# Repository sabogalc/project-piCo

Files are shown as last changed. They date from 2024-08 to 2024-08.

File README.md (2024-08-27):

# project piCo

This repository contains KiCad project files for reverse-engineered Raspberry Pi Pico boards, including both the standard RP2040 Pico H and the WiFi version, the Pico WH. There is also a preliminary design for an RP2350 Pico 2 board. The primary goal of this project is two-fold:

1. USB-C Upgrade: Although all Pico boards were released in or after 2021, they all use Micro-USB. The initial aim was to update these boards to include USB-C, making them more compatible with modern standards.

2. Accessibility of Design Files: During this process, I discovered that the original board designs are created in Cadence Allegro, a format that is less accessible due to its encrypted file structure and the expensive software required. This project not only adds USB-C support but also aims to make the design files as free and open as possible.

For detailed information on each board’s design, please refer to their specific folders within the `KiCad Projects` directory. Boardview files for all boards, including the original Pico H, are provided to allow for easy troubleshooting. The designs in this repository are freely available for use without any license restrictions or attribution requirements.

> The USB-C version of the Pico H board.


> The USB-C version of the Pico WH board.


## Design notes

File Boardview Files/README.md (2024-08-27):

# Boardview Files

### What is a boardview file?

A boardview file is a netlist of all the connections on a PCB with every component laid out exactly as it is in real life. This is a much more modern and easy approach to viewing connections and approaching troubleshooting than sifting through a schematic to figure out which parts and nets need to be connected to each other.

### How can I view these files?

Much like how there are many PCB EDA softwares out there, there are also many board viewing softwares. The two that I have used and recommend are the MIT licensed [OpenBoardView](https://github.com/OpenBoardView/OpenBoardView) or the commercial (with free version available) [FlexBV](https://pldaniels.com/flexbv/). Below is a screenshot of the Type-C Pico boardview when viewed from FlexBV.

Pico Boardview

You can see the VBUS net is selected, and everywhere that VBUS is present on the board lights up in green. There is also a table of every component and its pin number that has VBUS on the right-hand side. Other important information seen in this boardview is the designators for each part, as well as the value of every resistor and capacitor and the footprint for every component.

All of this metadata comes from the `.obdata` file, and as of August 2024, this metadata is only viewable in FlexBV, which is why I use it as opposed to OpenBoardView. However, the `.obdata` file format is an [open file format and initiative](https://openboarddata.org/), and I would very much like to see the feature added to OpenBoardView.

### How can I make boardview files for my own designs?

All of the boardview files I make for my projects are using [an open-source KiCad plugin](https://github.com/whitequark/kicad-boardview). When I first came across this plugin, it had a few bugs with current versions of KiCad, so I submitted some pull requests and the plugin is back into perfect operating condition. The `.obdata` generation script is currently internal since I made a bit of a mess [submitting that PR](https://github.com/whitequark/kicad-boardview/pull/16), but I am looking to release it eventually.

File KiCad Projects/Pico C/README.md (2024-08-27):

# project piCo

This is a completely reverse-engineered Raspberry Pi Pico H made in KiCad version 8. The Raspberry Pi Foundation offers schematics and board layout files for the original board, but they are made in Cadence Allegro, which costs a crisp $1,500/month that I do not have. Instead, I opted to recreate the board in KiCad so that I could add a Type-C port.

### Overview

Initially, I developed a PCB to convert the original Micro-USB signals to a Type-C breakout board. However, the tolerances were really tight, and it didn't look like much of a finished product. My boss gave me a suggestion to redesign the entire board and add a Type-C port to it, which is what I ended up doing. I started the process with the original design files, which you can find in the section below.

### Design Sources

- **Schematic:** [Raspberry Pi Pico Datasheet](https://datasheets.raspberrypi.com/pico/pico-datasheet.pdf#page=26)
- **PCB Design Files:** [RPi Pico R3 Files](https://datasheets.raspberrypi.com/pico/RPi-Pico-R3-PUBLIC-20200119.zip) (Note: This link will download files directly.)
- **BOM:** [Pico Bill of Materials](https://archive.is/NHUY5)

The mechanical layout provided by the Pi Foundation was extremely useful in creating my board dimensions. Since my footprint was made in KiCad, anybody should be able to implement it for their own projects.

### Footprint Differences

The project includes a footprint named "CON_PICO_40W," which replicates the original footprint, and a modified version, "CON_PICO_40W_VER_C," which is used in my design. Key differences are highlighted below.

Footprint Image

### Design Evolution

Version 1 of the board had many issues. You can see that version [here](https://github.com/sabogalc/project-piCo/tree/4ffbc08c13815f0195cdc85224667cf2c5e13563). The biggest challenge was fitting the Type-C port within the original dimensions.

When I published this project, many people let me know that Type-C Pico clones already exist, so I modeled my redesign after the purple clone board from [this AliExpress listing](https://www.aliexpress.com/item/3256805444428998.html).

AliExpress Board

The revised design removed the 4 mounting holes and added space for the Type-C port, which vastly improved my ability to design and route this board. The "CON_PICO_40W_VER_C" footprint used in this revision is a copy of the purple clone board. Sometimes you just need to [reverse-engineer the reverse-engineers](https://youtu.be/FVEQJNRmfDQ?t=431).

### Component Substitutions

I could not find the original boot select switch, Schottky diode, or 12MHz crystal in stock anywhere, but the substitutions I made should be plug-and-play.

### PDF Schematic

For those of you without KiCad or that just want to take a quick look at the schematic, a [PDF version](https://github.com/sabogalc/project-piCo/blob/main/KiCad%20Projects/Pico%20C/RPI-PICO-R3a-PUBLIC.pdf) is available.

### Version 4 - A 1:1 recreation

[Version 3](https://github.com/sabogalc/project-piCo/tree/0116e01858a51d29eb83f16cde15d637a825e509) of this board improved on [version 2](https://github.com/sabogalc/project-piCo/tree/e2333728981e60bb3f34c05a658cf739d1d45163) in regards to copper pours, routing, and silkscreen labeling. However, versions 1-3 were all routed from scratch by myself. As seen below in the `Official Files` section or in the [piCo W folder](https://github.com/sabogalc/project-piCo/tree/main/KiCad%20Projects/Pico%20WH%20-%20No%20License), I later learned how to convert a Cadence Allegro board into a KiCad one, and this allows me to make a 1:1 PCB when reverse-engineering. Version 4 is this 1:1 render, and it should theoretically be the last version of this board.
Version 4 Render

When it comes to improving the Pico, I have thought about making design improvements to the ADC or adding a reset switch. However, the overall purpose of this project is to be 1:1 with the layout and parts of an original Pico, though if anyone finds any room for improvement I would be happy to make any fixes (e.g. the grid on the schematic is not standard and could use correction).

_**DISCLAIMER**_

I have interned at this company for almost two years.

For those of you that want a board with the aforementioned improvements, check out the [RP2040 board from Out of the Box](https://www.ootbelec.com/store/p/ootb-rp2040).

### Official Files

I have updated this folder to include a file called `RPI-PICO-R3a-PUBLIC - Official.kicad_pcb`. This is as close to the original Cadence Allegro design file that I could get imported into KiCad. I first converted the Allegro board into an Altium one, and then I converted the Altium board into KiCad.

Converted Design
Coverted Design Close-up

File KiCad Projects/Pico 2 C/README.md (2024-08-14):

# project piCo 2

I was extremely excited to see the announcement of the Pico 2 last week, but some of my enthusiasm left me when I saw that the new board still retained the Micro-USB connector. Of course, I got right to work on correcting this issue.

### Design Sources

Despite the online documentation and datasheet linking to design files for the board, the link appears to be broken as of August 14, 2024. (See [this issue](https://github.com/raspberrypi/documentation/issues/3809) for more information)

Still, I worked with the schematic and pictures of the board to be able to create an initial version of a Type-C Pico 2.

- **Schematic:** [Raspberry Pi Pico 2 Datasheet](https://datasheets.raspberrypi.com/pico/pico-2-datasheet.pdf#page=23)
- **PCB Pictures (Front & Back):** [Pico 2 PCB Photos](https://blog.zonepi.cz/rapsberry-pi-pico-2/)

Thankfully, with all the work I've already done on reversing the Pico, making this board was a breeze as I was able to reuse many of my assets and resources from the previous boards.

### Design Process

Kicad allows for Reference Images to be placed while routing a board (found in `Place > Add Reference Image`), so I put the aforementioned scans into the project to scale, and based my routing on the photo. This means that my board is not fully 1:1 with the factory one, but in lieu of the official design files, this was the best that could be done right now. An example of this layout is shown below.


### Component Substitutions (IMPORTANT)

As-is, this board is not ready for production. I was unable to figure out what component or footprint L2 is, other than that it is a coupled inductor and measures roughly 1.75x2.2mm. As a stand-in, I have placed an 0602 SMD inductor, but please note that this is **_not correct_**. As before, the boot select switch and 12MHz crystals are compatible substitutes (even though they told us what crystal was used this time, I just reused the asset I already had from the previous design).

### PDF Schematic

A PDF copy of the schematic is available [here](https://github.com/sabogalc/project-piCo/blob/main/KiCad%20Projects/Pico%202%20C/Pico%202%20C.pdf).

### Board Photos

Because of the aforementioned inductor issue, the only photos of this board right now are the KiCad renders. If anybody figures out what inductor this is, please either let me know or make a correction in the form of a pull request.




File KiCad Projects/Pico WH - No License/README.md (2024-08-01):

# project piCo W

After a few months of making projects with the Pico, I found myself wanting to utilize some of the features offered by the Pico W. However, this meant that I would need to give the same USB-C reverse-engineering treatment to this board, so I took what I learned from my first go and remade the Pico WH as best I could. 

### Design Sources

- **Schematic:** [Raspberry Pi Pico W Schematic](https://wiki.amperka.ru/_media/products:raspberry-pi-pico-w:raspberry-pi-pico-w-schematic.pdf)
- **PCB Design Files:** [RPi PicoW Files](https://datasheets.raspberrypi.com/picow/RPi-PicoW-PUBLIC-20220607.zip) (Note: This link will download files directly.)

This time, rather than making my own board layout, I tried to follow the factory layout as closely as possible. Similarly to the [Official Files](https://github.com/sabogalc/project-piCo/tree/main/KiCad%20Projects/Pico%20C#official-files) section of the original Type-C Pico, I converted the factory Allegro files into a KiCad file (with an Altium conversion in between the two).

Converted Design Close-Up

I then used this converted board as the starting point for my board, so the final result is much closer to the original design. Unfortunately, I cannot release either the converted board or my initial design at this time for reasons that I will explain below.

### The Patent

On page 2 of the schematic, there is a note by the antenna arrangement that reads
> The Niche is an Abracon/Proant patented antenna technology. Please contact niche@abracon.com for information on licensing.

I sent an email explaining my project and how it wasn't commercial in any capacity, asking if there was any kind of fee I could pay to be able to release the board as is. The reponse I got read

> The licensed version of Niche is aimed for high volumes (>100kpcs), and there is a royalty fee/pcs which is agreed per project/customer. The idea is that it should be a very cost-effective solution for high-volume production. It is not an open-source solution which can be used without agreement with Abracon.

They did offer an alternative in the form of a stamped metal antenna that worked virtually identically and came with no license requirement, so I remade the board around this footprint (which is the one you can find in this folder). I found the patent [here](https://patentimages.storage.googleapis.com/39/da/99/a6a16469f1c9ba/US10910715.pdf), and though I am not a legal or patent expert, my understanding is that by 35 U.S.C. 154(b), this patent will expire on March 11, 2038, after which I will be okay to release all of the designs.

### Design Process

Though I am not releasing the design that is barred by the patent, I will still show photos of the final version of that board, and I have also released the boardview file for that board (neither one of these are remotely close to a finished PCB, so I'm sure that is fine). Below is a photo of both boards, with the royalty-free design on the left and the closer 1:1 design on the right.



My design process was essentially Alt+Tabbing between a window that had the converted Allegro design and my blank PCB and just building it up piece by piece while following the design specifications from the import. I did have to make some changes in order to get the board manufactured such as slightly decreasing the diameter of the BGA balls for the WiFi chip, but the final result is still very close to the original parameters.

Unfortunately, because of how many vias this board has, the tight routing, and the fact that it is four layers, it costs about $70-75 USD to get 10 of them manufactured, and then to be able to populate them raises the price even more, so it is not very financially sound to order and make this board. Regardless, these design files should still prove useful as an educational resource.

### Component Substitutions

As with the original project piCo, the boot select switch, Schottky diode, and 12MHz crystal in my design are not the exact ones that the Pi Foundation used, but they are compatible substitutes.

### PDF Schematic

A PDF copy of the schematic is available [here](https://github.com/sabogalc/project-piCo/blob/main/KiCad%20Projects/Pico%20WH%20-%20No%20License/Pico%20WH.pdf).

### Board Photos

Below are the renders of the board in KiCad, as well as individual photos of them in real life.

- **KiCad Render - Original:** KiCad Render - Original
- **KiCad Render - No License:** KiCad Render - No License

- **Pico WH:** Pico WH
- **Pico WH - No License:** Pico WH - No License

### Future Enhancements

A version of this board with a non-patented antenna could be developed. Similar designs are available in Chinese clone boards, such as the one in [this AliExpress listing](https://www.aliexpress.com/item/3256805996726845.html). If anyone would like to submit a pull request with changes like this one, I would be happy to merge it.

Pico W Clone

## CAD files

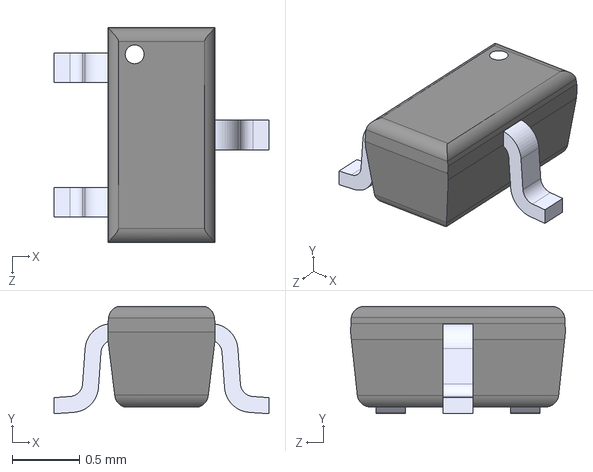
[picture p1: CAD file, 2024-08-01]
KiCad Projects/Pico 2 C/STEP files/DMG1012T-7.step
1.60 x 0.8 x 1.60 mm

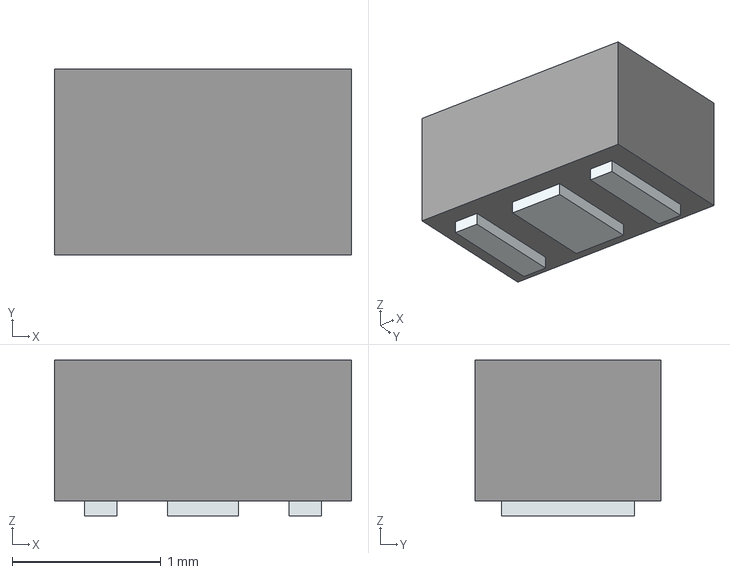
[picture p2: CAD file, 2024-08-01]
KiCad Projects/Pico WH - No License/STEP files/LFB212G45CG7D227.stp
2.00 x 1.25 x 1.05 mm
Pins

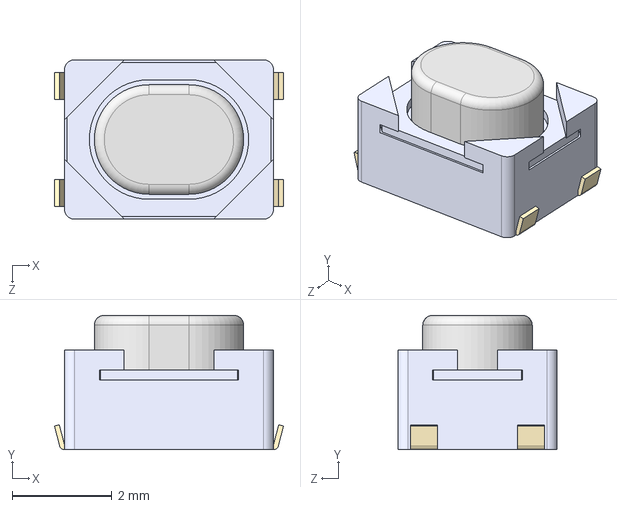
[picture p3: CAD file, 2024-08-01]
KiCad Projects/Pico 2 C/STEP files/SW_SPST_PTS810.step
4.60 x 2.70 x 3.20 mm

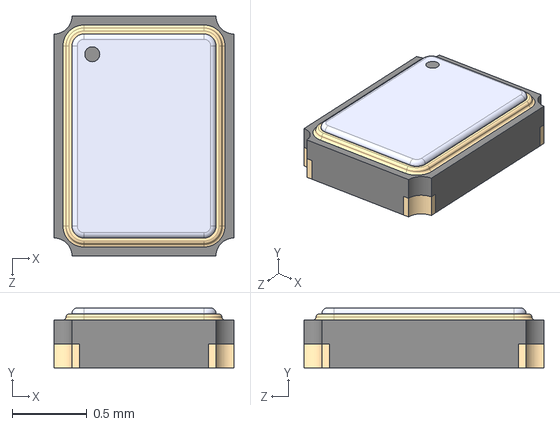
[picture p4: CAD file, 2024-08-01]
KiCad Projects/Pico WH - No License/STEP files/8Q-37.400MEEE-T.step
1.20 x 0.4 x 1.60 mm

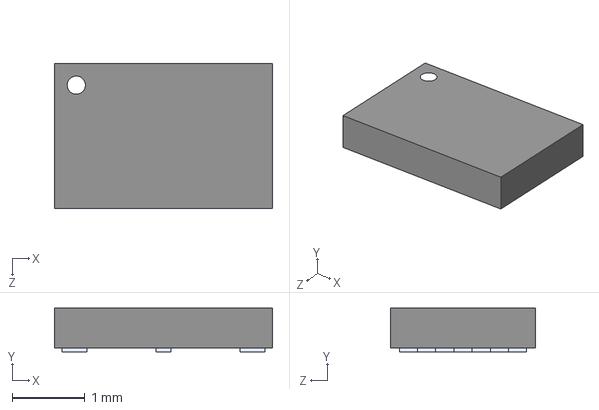
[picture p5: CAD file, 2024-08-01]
KiCad Projects/Pico 2 C/STEP files/W25Q16JVUXIQ.step
3.00 x 0.6 x 2.00 mm

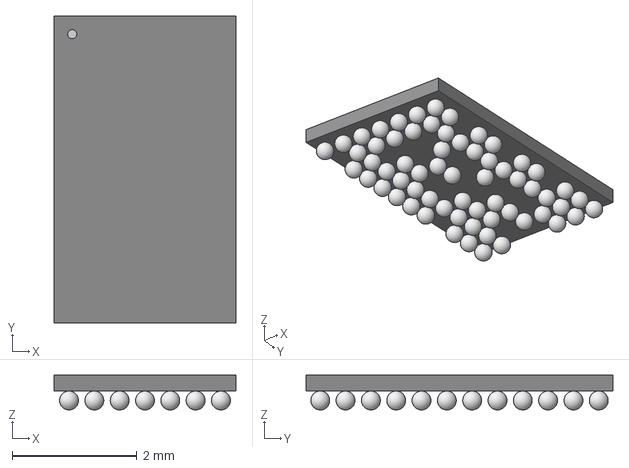
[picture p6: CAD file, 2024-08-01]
KiCad Projects/Pico WH - No License/STEP files/BGA-63.step
2.92 x 4.93 x 0.561 mm

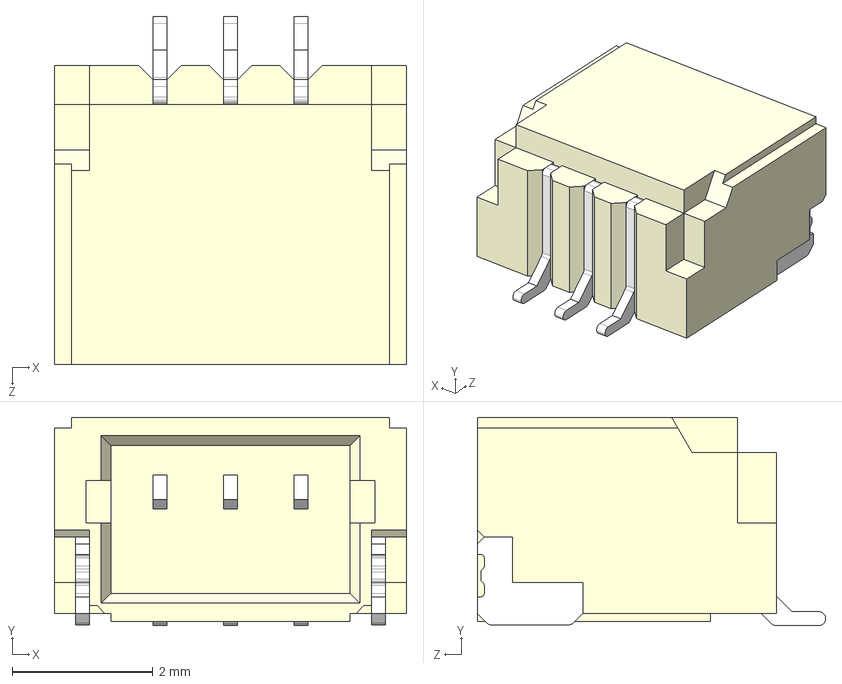
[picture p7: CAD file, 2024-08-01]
KiCad Projects/Pico 2 C/STEP files/SM03B-SRSS-TB_LF__SN_.step
5.00 x 2.96 x 4.95 mm

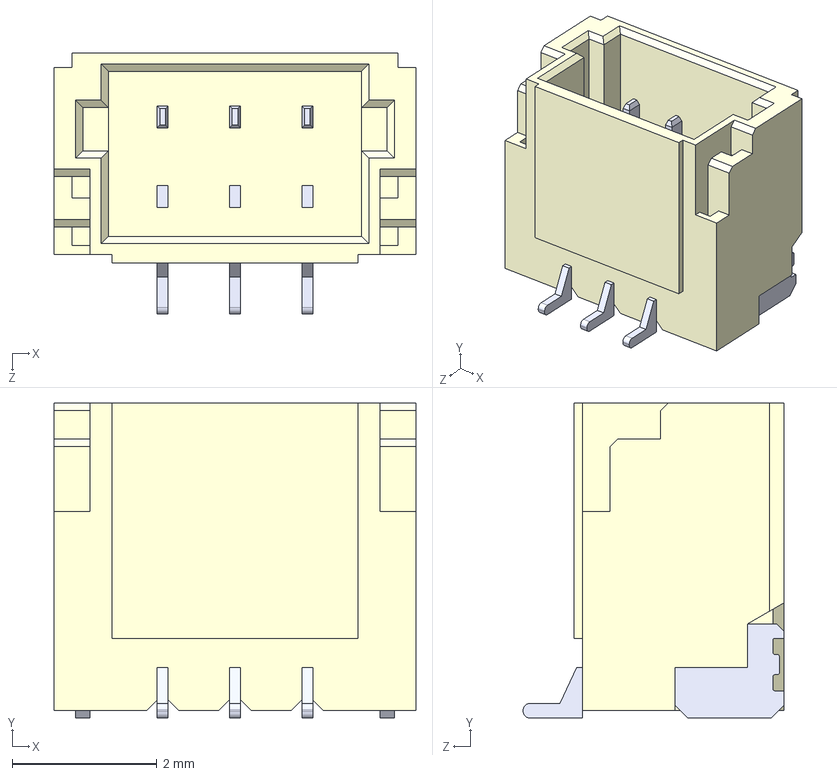
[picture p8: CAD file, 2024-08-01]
KiCad Projects/Pico WH - No License/STEP files/BM03B-SRSS-TB-LF--SN---3DModel-STEP-56544.STEP
5.00 x 4.35 x 3.60 mm

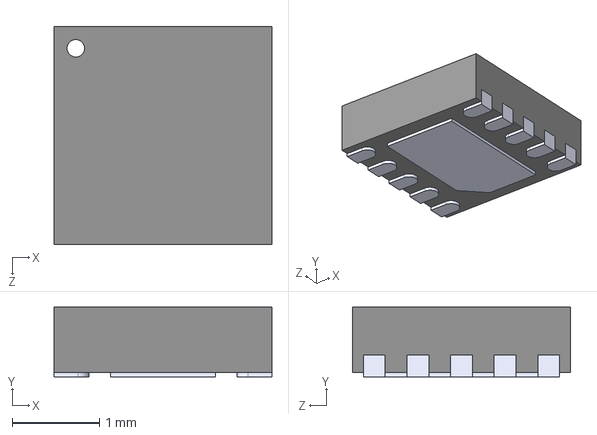
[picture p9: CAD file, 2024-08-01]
KiCad Projects/Pico 2 C/STEP files/RT6150B-33GQW.step
2.50 x 0.8 x 2.50 mm

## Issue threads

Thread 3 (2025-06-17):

Inductor update request

miraclehoshi, 2025-06-17:
As-is, this board is not ready for production. I was unable to figure out what component or footprint L2 is, other than that it is a coupled inductor and measures roughly 1.75x2.2mm. As a stand-in, I have placed an 0602 SMD inductor, but please note that this is not correct. As before, the boot select switch and 12MHz crystals are compatible substitutes (even though they told us what crystal was used this time, I just reused the asset I already had from the previous design).

Regarding the L2 inductor, the correct component is specified on page 454 of the RP2350 datasheet. (https://datasheets.raspberrypi.com/rp2350/rp2350-datasheet.pdf)
The part number is AOTAB201610S3R3-101-T, and according to the datasheet (https://abracon.com/datasheets/AOTA-B201610S3R3-101-T.pdf),
it is "Approved for use with Raspberry Pi’s RP235x range of microcontroller products."

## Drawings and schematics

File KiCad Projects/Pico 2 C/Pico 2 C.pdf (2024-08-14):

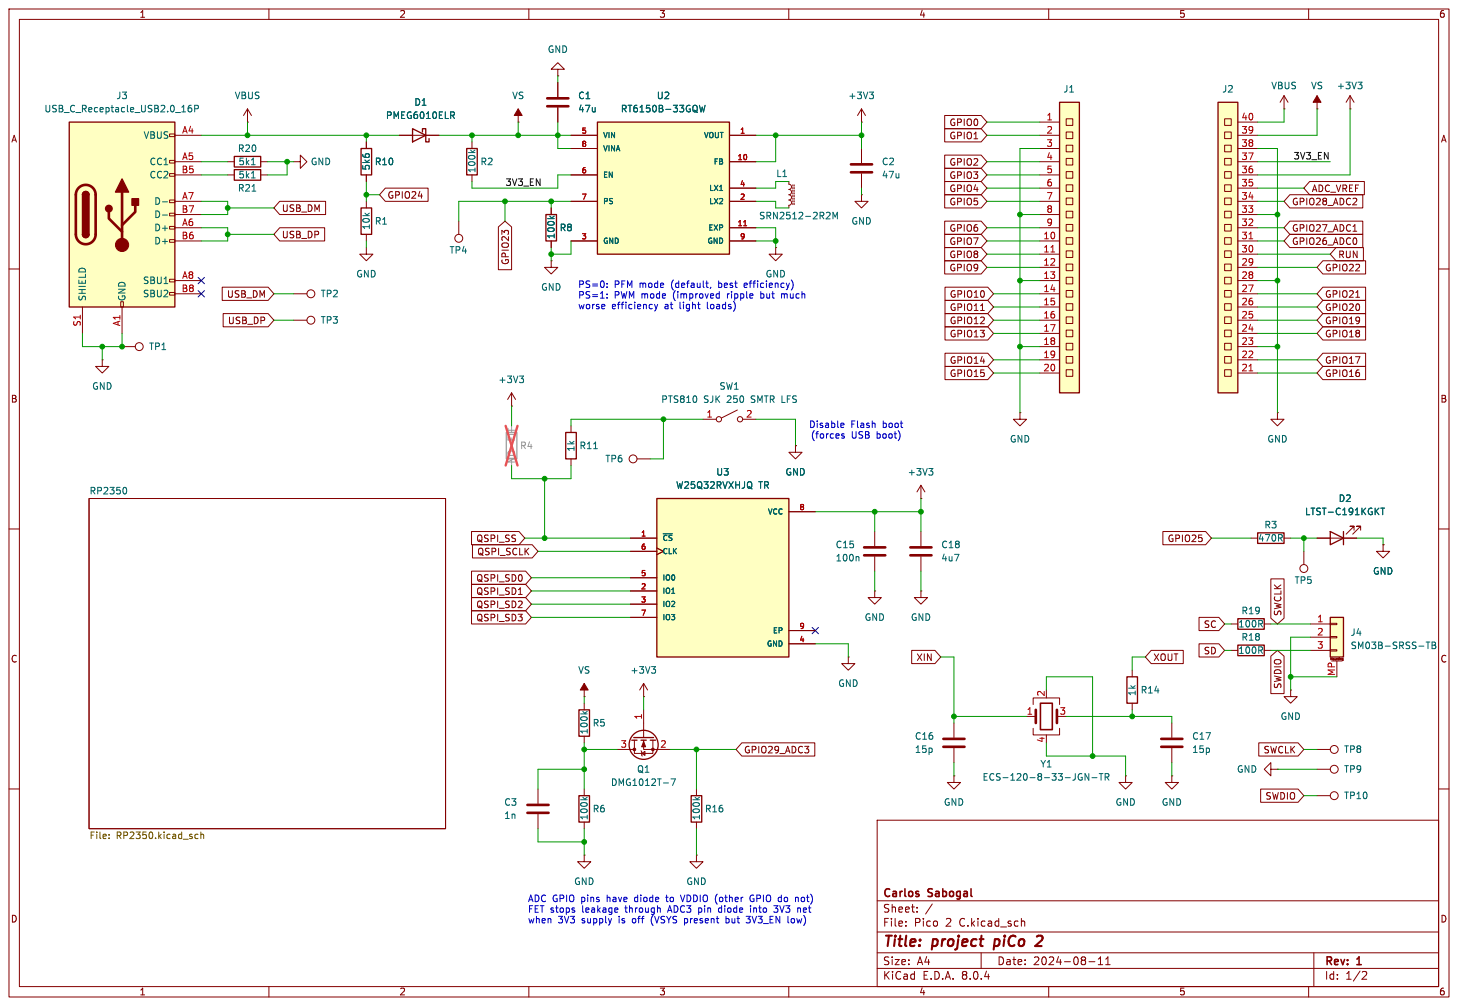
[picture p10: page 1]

File: Pico 2 C.kicad_sch Sheet: / Carlos Sabogal RP2350 File: RP2350.kicad_sch

Id: 1/2 Title: project piCo 2

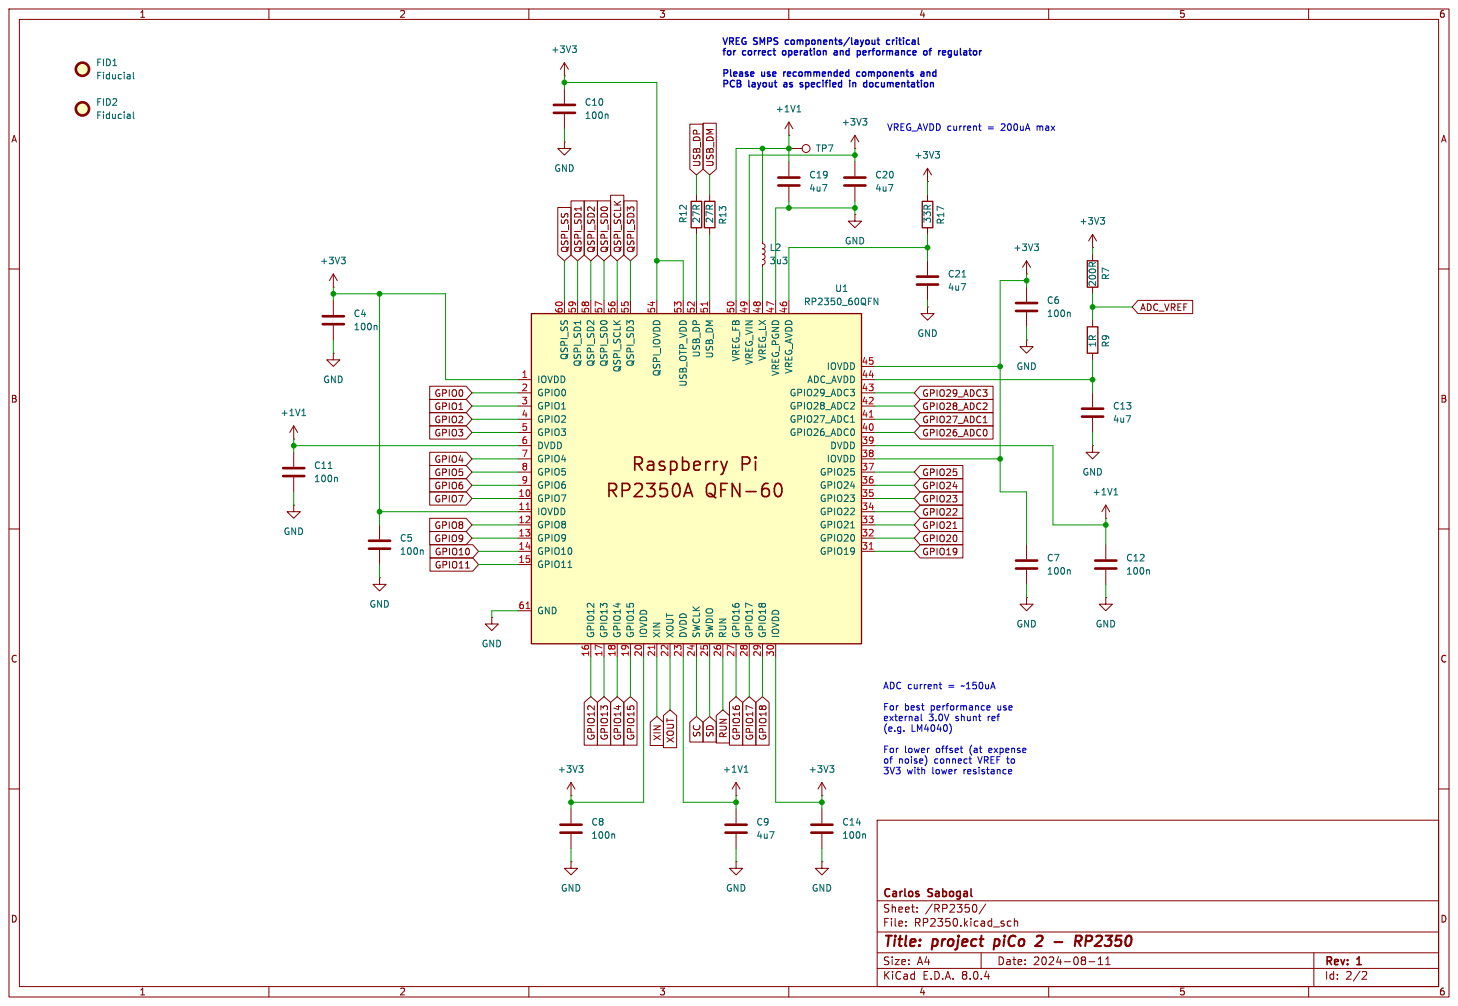
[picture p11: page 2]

of noise) connect VREF to
3V3 with lower resistance

File: RP2350.kicad_sch Sheet: /RP2350/ Carlos Sabogal

Id: 2/2 Title: project piCo 2 - RP2350

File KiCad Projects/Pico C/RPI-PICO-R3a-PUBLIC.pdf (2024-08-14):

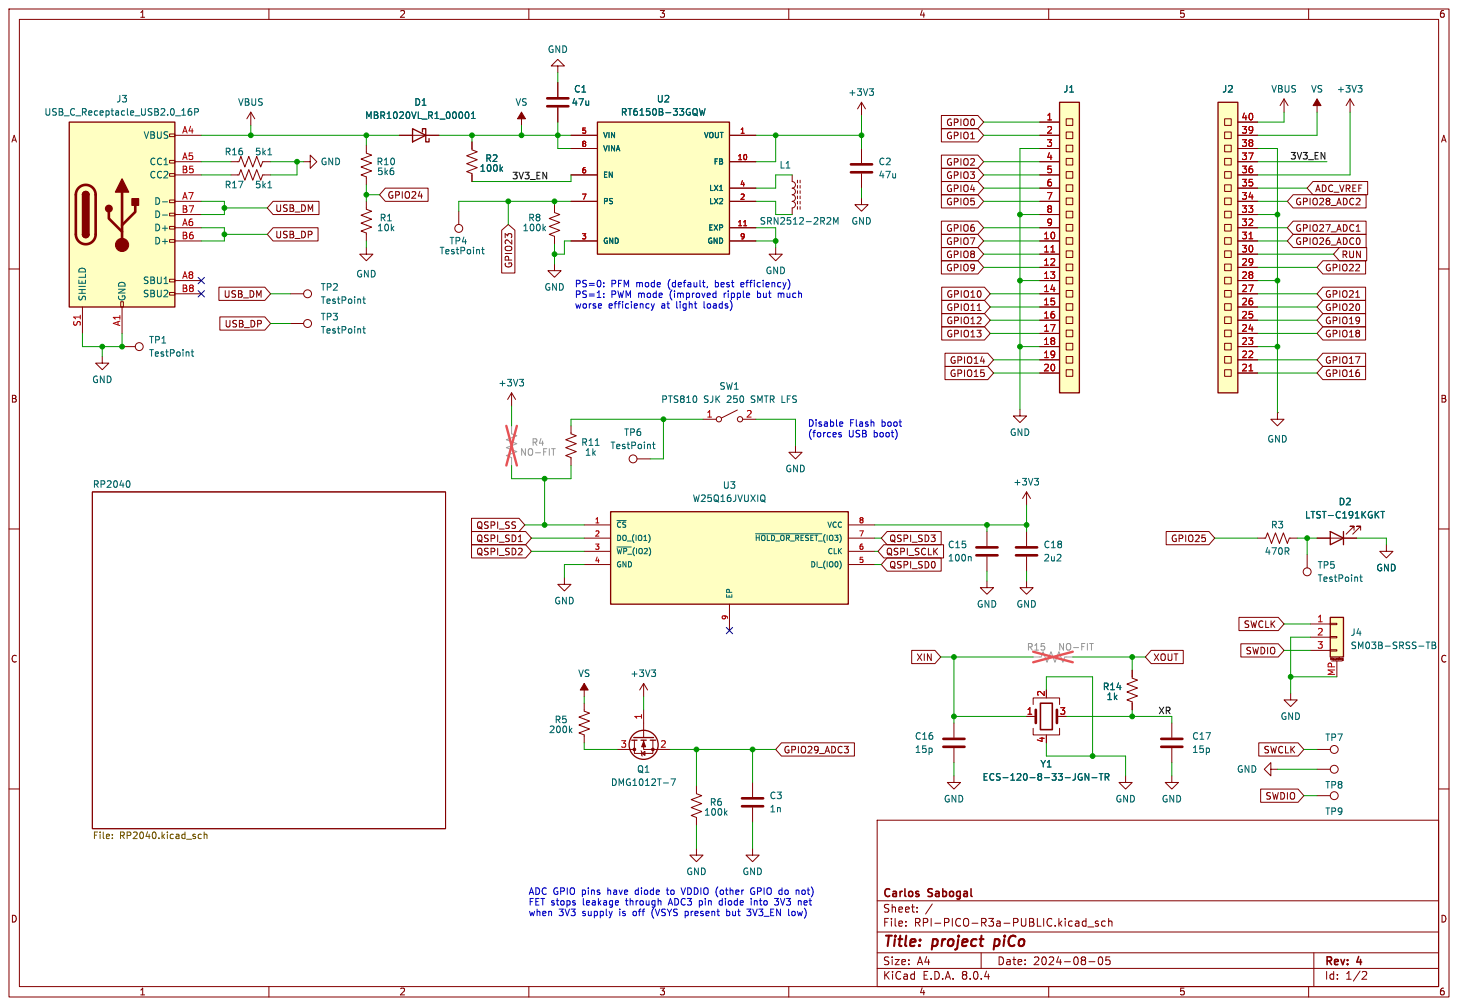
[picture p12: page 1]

Disable Flash boot (forces USB boot) U2 RT6150B-33GQW

Id: 1/2 Title: project piCo

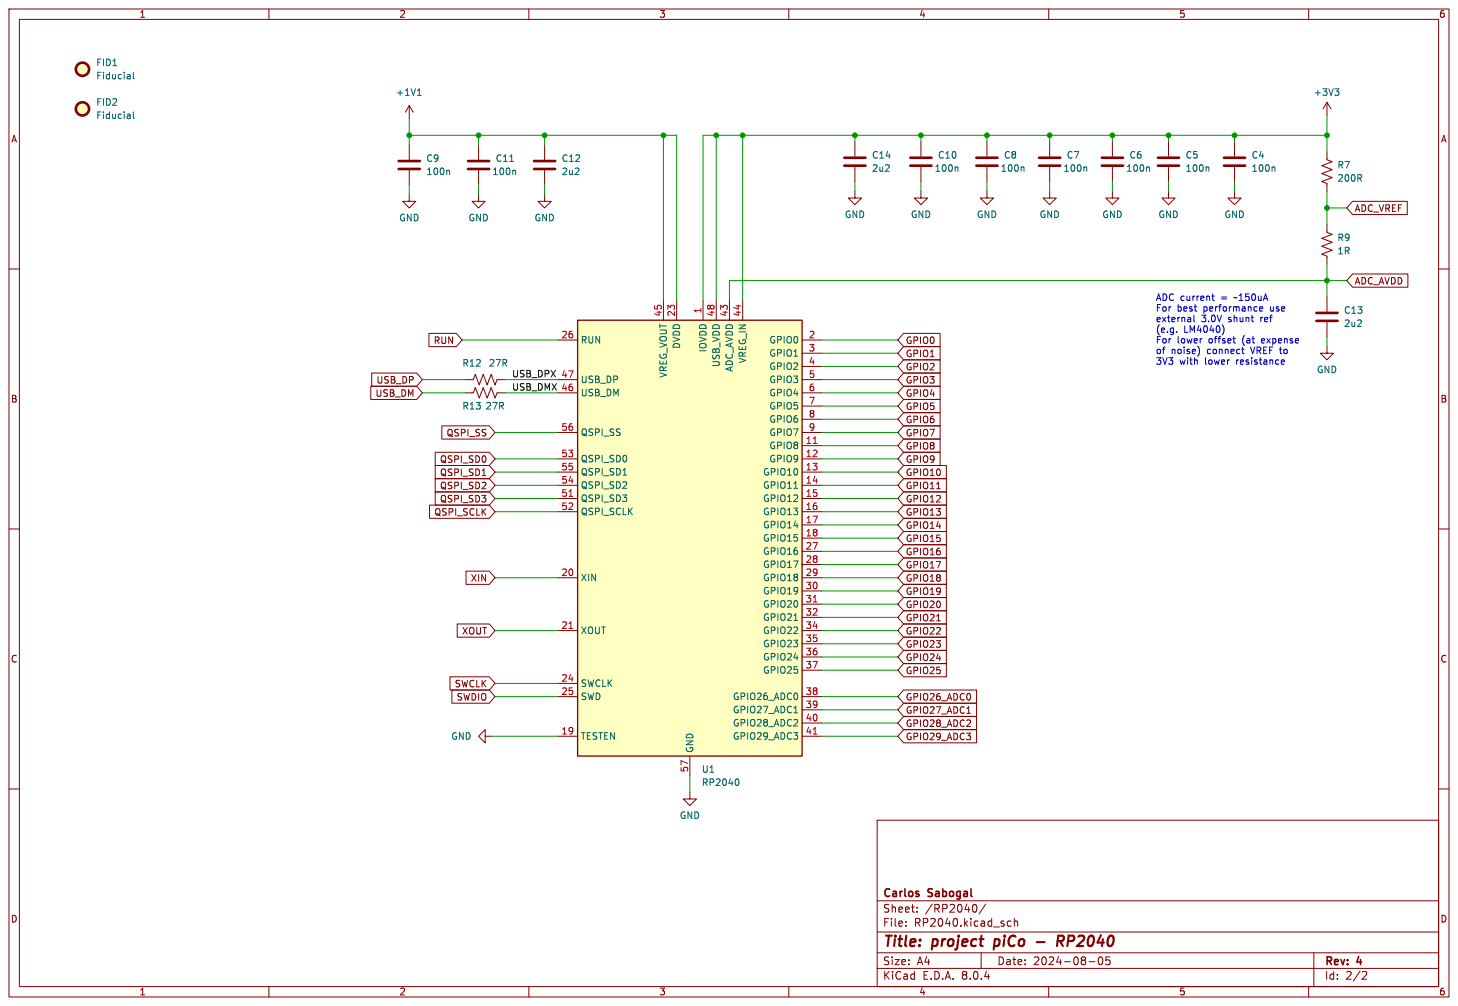
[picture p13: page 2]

of noise) connect VREF to
3V3 with lower resistance

File: RP2040.kicad_sch Sheet: /RP2040/ Carlos Sabogal

Id: 2/2 Title: project piCo - RP2040

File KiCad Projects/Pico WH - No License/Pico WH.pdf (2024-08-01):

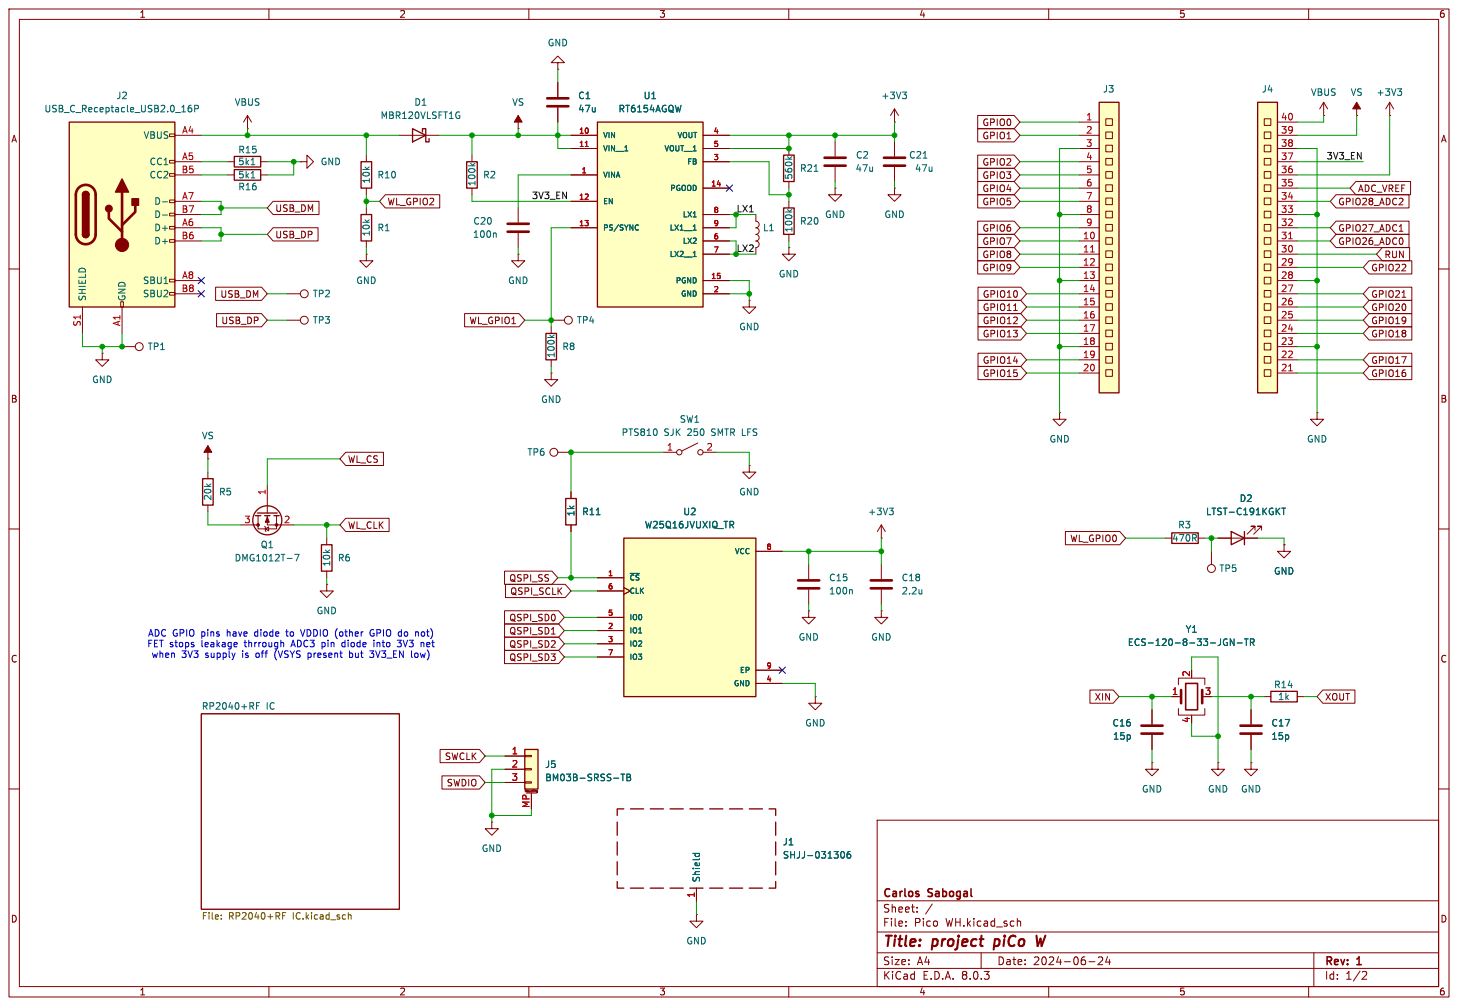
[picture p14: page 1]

4 Y1 ECS-120-8-33-JGN-TR GND GND

Id: 1/2 Title: project piCo W

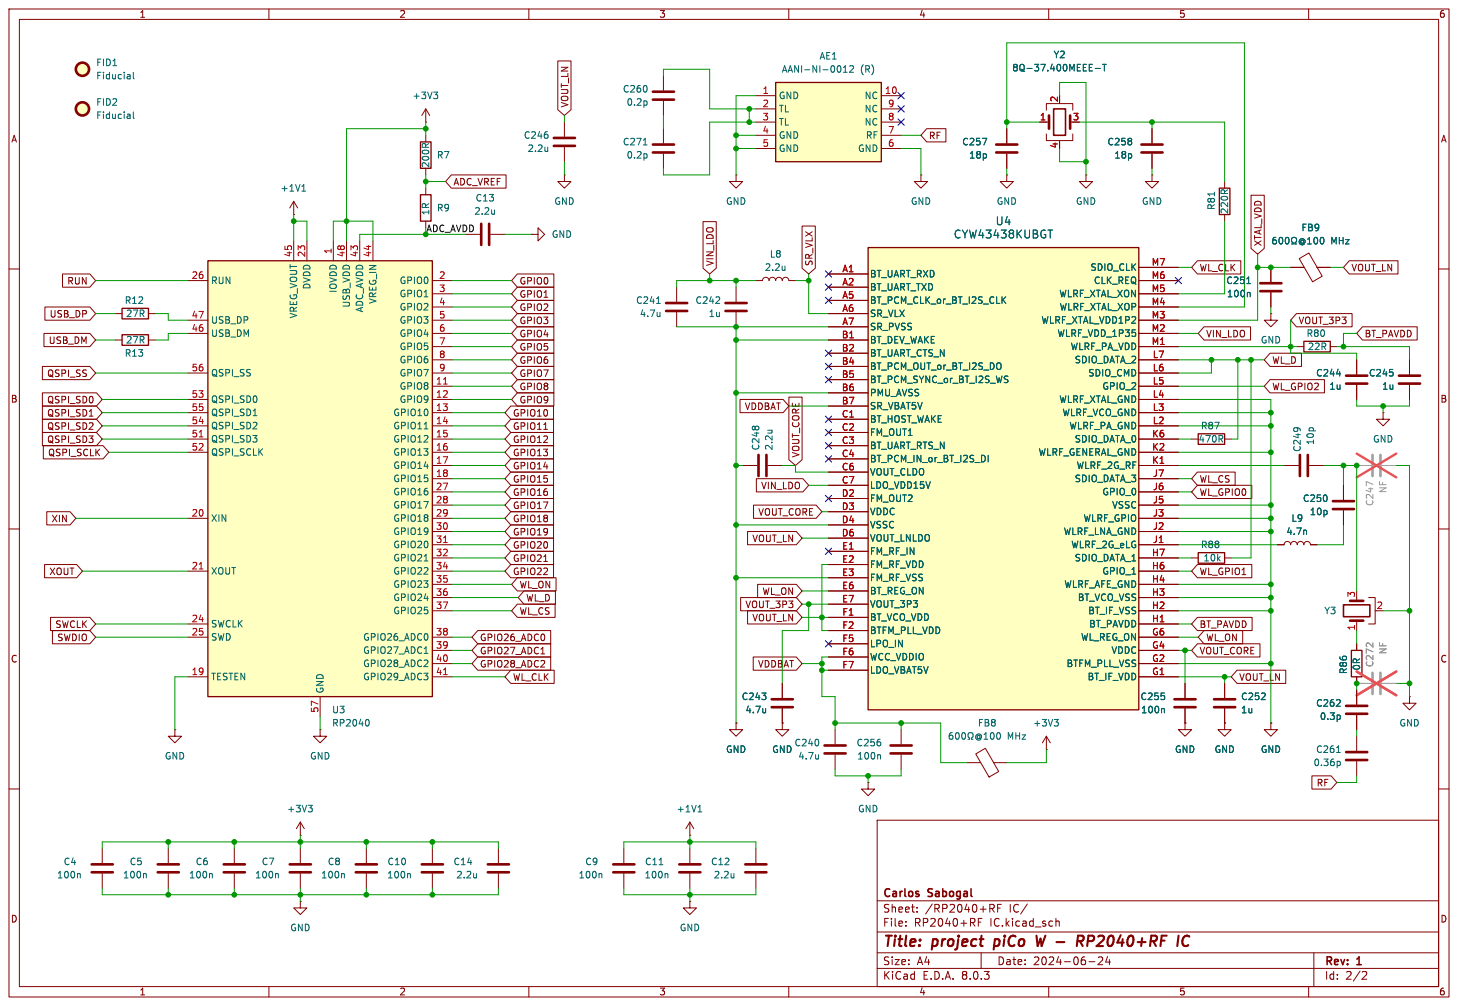
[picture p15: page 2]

1 GPIO8 11 GPIO9 12 GPIO10 13 GPIO11 14 GPIO12 15 GPIO13 16 GPIO14 17 GPIO15 18 TESTEN 19 GPIO0 2 XIN 20 XOUT 21 DVDD 23 SWCLK 24 SWD 25 RUN 26 GPIO16 27 GPIO17 28 GPIO18 29 GPIO1 3 GPIO19 30 GPIO20 31 GPIO21 32 GPIO22 34 GPIO23 35 GPIO24 36 GPIO25 37 GPIO26_ADC0 38 GPIO27_ADC1 39 GPIO2 4 GPIO28_ADC2 40 GPIO29_ADC3 41 ADC_AVDD 43 VREG_IN 44 VREG_VOUT 45 USB_DM 46 USB_DP 47 USB_VDD 48 GPIO3 5 QSPI_SD3 51 QSPI_SCLK 52 QSPI_SD0 53 QSPI_SD2 54 QSPI_SD1 55 QSPI_SS 56 GND 57 GPIO4 6 GPIO5 7 GPIO6 8 GPIO7 9 U3 RP2040 GND

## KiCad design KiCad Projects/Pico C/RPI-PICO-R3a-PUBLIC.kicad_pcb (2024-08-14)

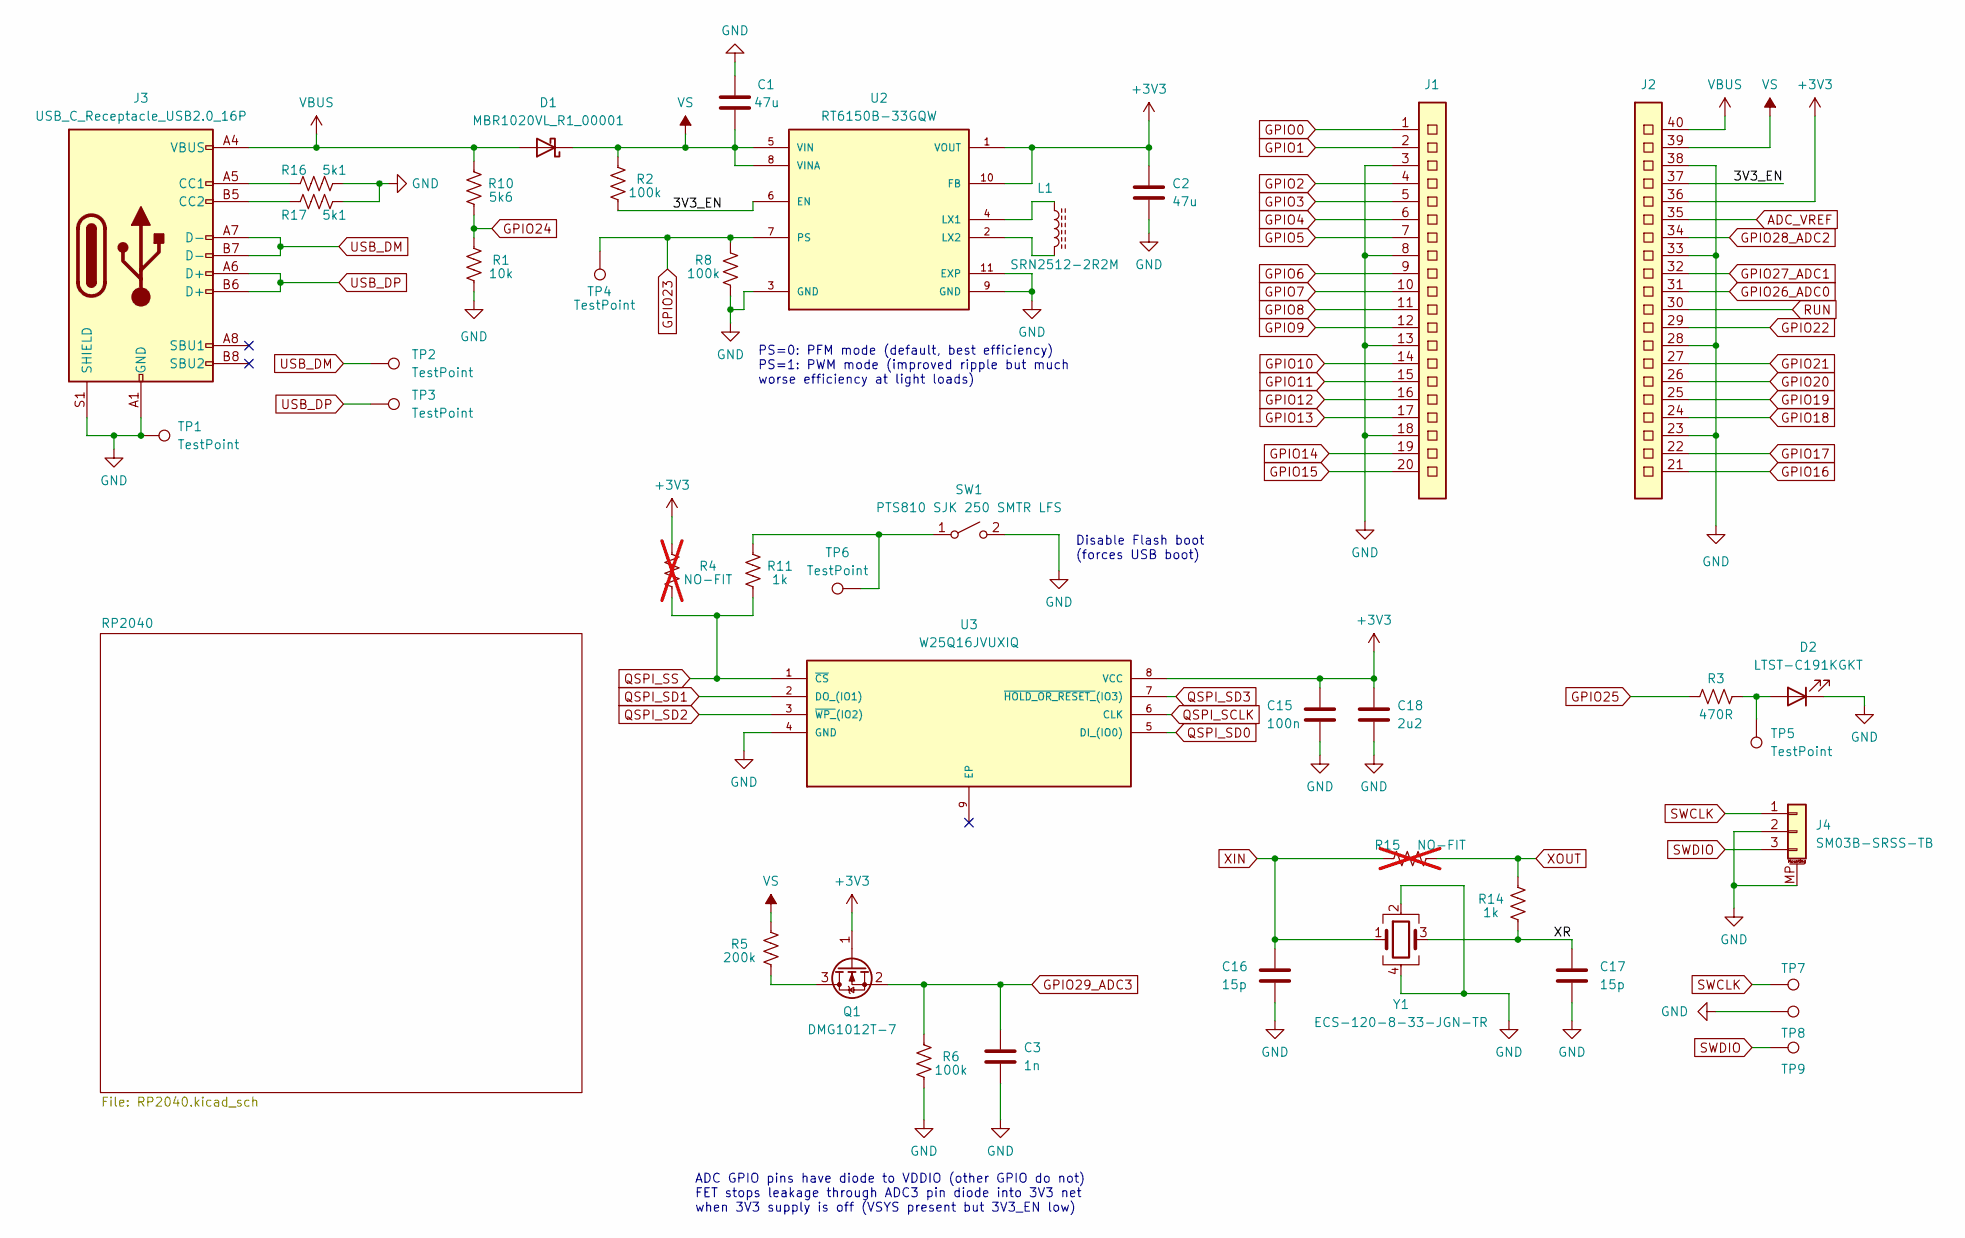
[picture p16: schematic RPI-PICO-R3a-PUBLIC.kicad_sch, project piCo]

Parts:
C1, C2: 47u; C_0805_2012Metric
C3: 1n; C_0201_0603Metric
C15: 100n; C_0201_0603Metric
C16, C17: 15p; C_0201_0603Metric
C18: 2u2; C_0402_1005Metric
D1: MBR1020VL_R1_00001; D_SOD-123F
D2: LTST-C191KGKT; LED_0603_1608Metric
J1: CON_PICO_1-20
J2: CON_PICO_21-40
J3: USB_C_Receptacle_USB2.0_16P; USB_C_Receptacle_GCT_USB4105-xx-A_16P_TopMnt_Horizontal
J4: SM03B-SRSS-TB; JST_SH_SM03B-SRSS-TB_1x03-1MP_P1.00mm_Horizontal
L1: SRN2512-2R2M; L_1008_2520Metric
Q1: DMG1012T-7; SOT-523
R1: 10k; R_0402_1005Metric
R2, R6, R8: 100k; R_0402_1005Metric
R3: 470R; R_0402_1005Metric
R4, R15: NO-FIT; R_0402_1005Metric; not fitted
R5: 200k; R_0402_1005Metric
R10: 5k6; R_0402_1005Metric
R11, R14: 1k; R_0402_1005Metric
R16, R17: 5k1; R_0402_1005Metric
SW1: PTS810 SJK 250 SMTR LFS; SW_SPST_PTS810
TP1, TP2, TP3, TP4, TP5, TP6, TP7, TP8, TP9: TestPoint; TestPoint_Pad_1.5x1.5mm
U2: RT6150B-33GQW; DFN-10-1EP_2.6x2.6mm_P0.5mm_EP1.3x2.2mm
U3: W25Q16JVUXIQ; SON50P300X200X60-9N
Y1: ECS-120-8-33-JGN-TR; Crystal_SMD_SeikoEpson_FA238-4Pin_3.2x2.5mm

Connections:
+3V3: C2.1, C15.1, C18.1, J2.36, Q1.1 (G), R4.2, U2.1 (VOUT), U2.10 (FB), U3.8 (VCC); also elsewhere on the board
/3V3_EN: J2.37, R2.1, U2.6 (EN)
/XR: C17.1, R14.1, Y1.3
ADC_VREF: J2.35; also elsewhere on the board
GND: C1.2, C2.2, C3.2, C15.2, C16.2, C17.2, C18.2, D2.1 (K), J1.3, J1.8, J1.13, J1.18, J2.23, J2.28, J2.33, J2.38, J3.A1 (GND), J3.A12 (GND), J3.B1 (GND), J3.B12 (GND), J3.S1 (SHIELD), J4.2, J4.MP (MountPin), R1.1, R6.1, R8.2, R16.2, R17.2, SW1.2 (B), TP1.1, TP8.1, U2.3 (GND), U2.9 (GND), U2.11 (EXP), U3.4 (GND), Y1.2, Y1.4; also elsewhere on the board
GPIO0: J1.1; also elsewhere on the board
GPIO1: J1.2; also elsewhere on the board
GPIO2: J1.4; also elsewhere on the board
GPIO3: J1.5; also elsewhere on the board
GPIO4: J1.6; also elsewhere on the board
GPIO5: J1.7; also elsewhere on the board
GPIO6: J1.9; also elsewhere on the board
GPIO7: J1.10; also elsewhere on the board
GPIO8: J1.11; also elsewhere on the board
GPIO9: J1.12; also elsewhere on the board
GPIO10: J1.14; also elsewhere on the board
GPIO11: J1.15; also elsewhere on the board
GPIO12: J1.16; also elsewhere on the board
GPIO13: J1.17; also elsewhere on the board
GPIO14: J1.19; also elsewhere on the board
GPIO15: J1.20; also elsewhere on the board
GPIO16: J2.21; also elsewhere on the board
GPIO17: J2.22; also elsewhere on the board
GPIO18: J2.24; also elsewhere on the board
GPIO19: J2.25; also elsewhere on the board
GPIO20: J2.26; also elsewhere on the board
GPIO21: J2.27; also elsewhere on the board
GPIO22: J2.29; also elsewhere on the board
GPIO23: R8.1, TP4.1, U2.7 (PS); also elsewhere on the board
GPIO24: R1.2, R10.1; also elsewhere on the board
GPIO25: R3.1; also elsewhere on the board
GPIO26_ADC0: J2.31; also elsewhere on the board
GPIO27_ADC1: J2.32; also elsewhere on the board
GPIO28_ADC2: J2.34; also elsewhere on the board
GPIO29_ADC3: C3.1, Q1.2 (S), R6.2; also elsewhere on the board
unnamed: D2.2 (A), R3.2, TP5.1
unnamed: J3.A5 (CC1), R16.1
unnamed: J3.B5 (CC2), R17.1
unnamed: Q1.3 (D), R5.1
unnamed: R11.2, SW1.1 (A), TP6.1
unnamed: L1.1, U2.4 (LX1)
unnamed: L1.2, U2.2 (LX2)
QSPI_SCLK: U3.6 (CLK); also elsewhere on the board
QSPI_SD0: U3.5 (DI_(IO0)); also elsewhere on the board
QSPI_SD1: U3.2 (DO_(IO1)); also elsewhere on the board
QSPI_SD2: U3.3 (~WP_(IO2)); also elsewhere on the board
QSPI_SD3: U3.7 (~HOLD_OR_RESET_(IO3)); also elsewhere on the board
QSPI_SS: R4.1, R11.1, U3.1 (~CS); also elsewhere on the board
RUN: J2.30; also elsewhere on the board
SWCLK: J4.1, TP7.1; also elsewhere on the board
SWDIO: J4.3, TP9.1; also elsewhere on the board
USB_DM: J3.A7 (D-), J3.B7 (D-), TP2.1; also elsewhere on the board
USB_DP: J3.A6 (D+), J3.B6 (D+), TP3.1; also elsewhere on the board
VBUS: D1.2 (A), J2.40, J3.A4 (VBUS), J3.A9 (VBUS), J3.B4 (VBUS), J3.B9 (VBUS), R10.2
VS: C1.1, D1.1 (K), J2.39, R2.2, R5.2, U2.5 (VIN), U2.8 (VINA)
XIN: C16.1, R15.1, Y1.1; also elsewhere on the board
XOUT: R14.2, R15.2; also elsewhere on the board

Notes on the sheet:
PS=0: PFM mode (default, best efficiency) PS=1: PWM mode (improved ripple but much worse efficiency at light loads)
ADC GPIO pins have diode to VDDIO (other GPIO do not) FET stops leakage through ADC3 pin diode into 3V3 net when 3V3 supply is off (VSYS present but 3V3_EN low)
Disable Flash boot (forces USB boot)

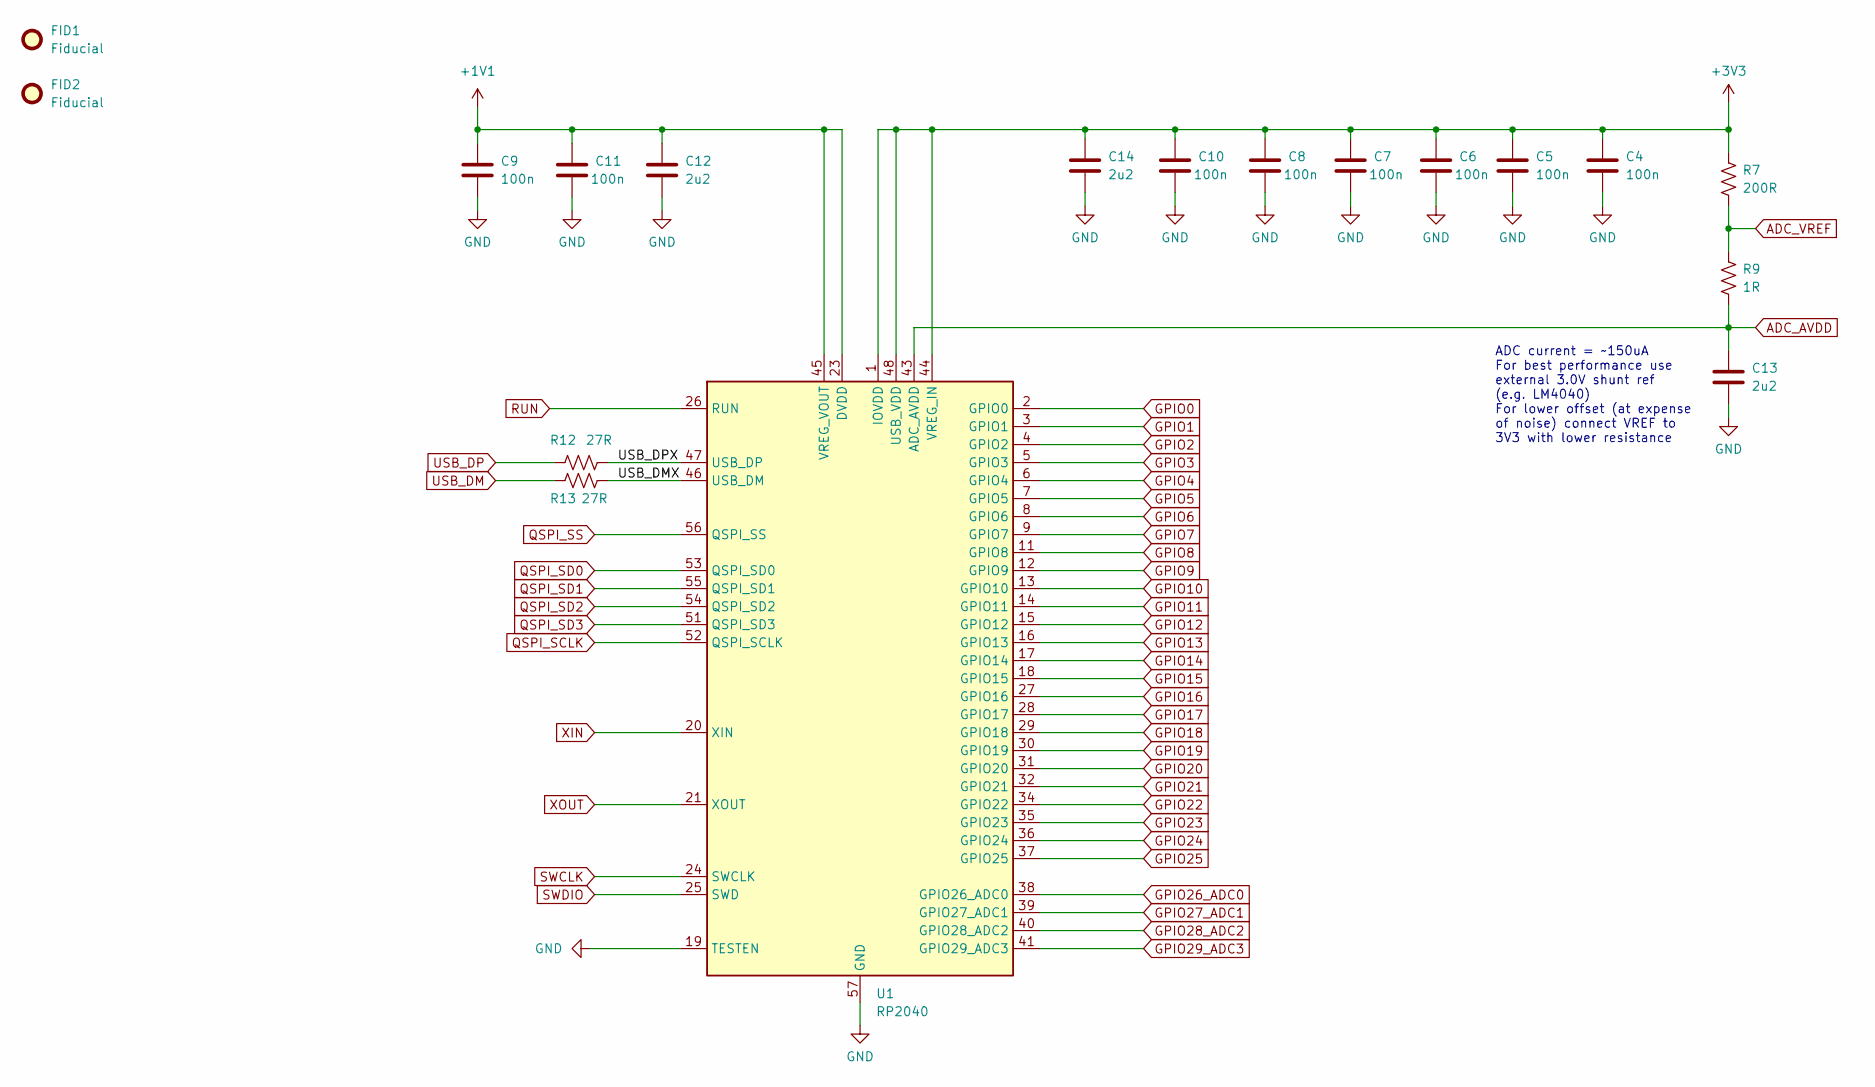
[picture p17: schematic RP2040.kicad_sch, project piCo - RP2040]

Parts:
C4, C5, C6, C7, C8, C9, C10, C11: 100n; C_0201_0603Metric
C12, C13, C14: 2u2; C_0402_1005Metric
FID1, FID2: Fiducial; Fiducial_1mm_Mask2mm
R7: 200R; R_0603_1608Metric
R9: 1R; R_0402_1005Metric
R12, R13: 27R; R_0201_0603Metric
U1: RP2040; QFN-56-1EP_7x7mm_P0.4mm_EP3.2x3.2mm

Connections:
+1V1: C9.1, C11.1, C12.1, U1.23 (DVDD), U1.45 (VREG_VOUT), U1.50 (DVDD)
+3V3: C4.1, C5.1, C6.1, C7.1, C8.1, C10.1, C14.1, R7.1, U1.1 (IOVDD), U1.10 (IOVDD), U1.22 (IOVDD), U1.33 (IOVDD), U1.42 (IOVDD), U1.44 (VREG_IN), U1.48 (USB_VDD), U1.49 (IOVDD); also elsewhere on the board
/RP2040/USB_DMX: R13.2, U1.46 (USB_DM)
/RP2040/USB_DPX: R12.2, U1.47 (USB_DP)
ADC_AVDD: C13.1, R9.2, U1.43 (ADC_AVDD)
ADC_VREF: R7.2, R9.1; also elsewhere on the board
GND: C4.2, C5.2, C6.2, C7.2, C8.2, C9.2, C10.2, C11.2, C12.2, C13.2, C14.2, U1.19 (TESTEN), U1.57 (GND); also elsewhere on the board
GPIO0: U1.2 (GPIO0); also elsewhere on the board
GPIO1: U1.3 (GPIO1); also elsewhere on the board
GPIO2: U1.4 (GPIO2); also elsewhere on the board
GPIO3: U1.5 (GPIO3); also elsewhere on the board
GPIO4: U1.6 (GPIO4); also elsewhere on the board
GPIO5: U1.7 (GPIO5); also elsewhere on the board
GPIO6: U1.8 (GPIO6); also elsewhere on the board
GPIO7: U1.9 (GPIO7); also elsewhere on the board
GPIO8: U1.11 (GPIO8); also elsewhere on the board
GPIO9: U1.12 (GPIO9); also elsewhere on the board
GPIO10: U1.13 (GPIO10); also elsewhere on the board
GPIO11: U1.14 (GPIO11); also elsewhere on the board
GPIO12: U1.15 (GPIO12); also elsewhere on the board
GPIO13: U1.16 (GPIO13); also elsewhere on the board
GPIO14: U1.17 (GPIO14); also elsewhere on the board
GPIO15: U1.18 (GPIO15); also elsewhere on the board
GPIO16: U1.27 (GPIO16); also elsewhere on the board
GPIO17: U1.28 (GPIO17); also elsewhere on the board
GPIO18: U1.29 (GPIO18); also elsewhere on the board
GPIO19: U1.30 (GPIO19); also elsewhere on the board
GPIO20: U1.31 (GPIO20); also elsewhere on the board
GPIO21: U1.32 (GPIO21); also elsewhere on the board
GPIO22: U1.34 (GPIO22); also elsewhere on the board
GPIO23: U1.35 (GPIO23); also elsewhere on the board
GPIO24: U1.36 (GPIO24); also elsewhere on the board
GPIO25: U1.37 (GPIO25); also elsewhere on the board
GPIO26_ADC0: U1.38 (GPIO26_ADC0); also elsewhere on the board
GPIO27_ADC1: U1.39 (GPIO27_ADC1); also elsewhere on the board
GPIO28_ADC2: U1.40 (GPIO28_ADC2); also elsewhere on the board
GPIO29_ADC3: U1.41 (GPIO29_ADC3); also elsewhere on the board
QSPI_SCLK: U1.52 (QSPI_SCLK); also elsewhere on the board
QSPI_SD0: U1.53 (QSPI_SD0); also elsewhere on the board
QSPI_SD1: U1.55 (QSPI_SD1); also elsewhere on the board
QSPI_SD2: U1.54 (QSPI_SD2); also elsewhere on the board
QSPI_SD3: U1.51 (QSPI_SD3); also elsewhere on the board
QSPI_SS: U1.56 (QSPI_SS); also elsewhere on the board
RUN: U1.26 (RUN); also elsewhere on the board
SWCLK: U1.24 (SWCLK); also elsewhere on the board
SWDIO: U1.25 (SWD); also elsewhere on the board
USB_DM: R13.1; also elsewhere on the board
USB_DP: R12.1; also elsewhere on the board
XIN: U1.20 (XIN); also elsewhere on the board
XOUT: U1.21 (XOUT); also elsewhere on the board

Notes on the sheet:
ADC current = ~150uA For best performance use external 3.0V shunt ref (e.g. LM4040) For lower offset (at expense of noise) connect VREF to 3V3 with lower resistance

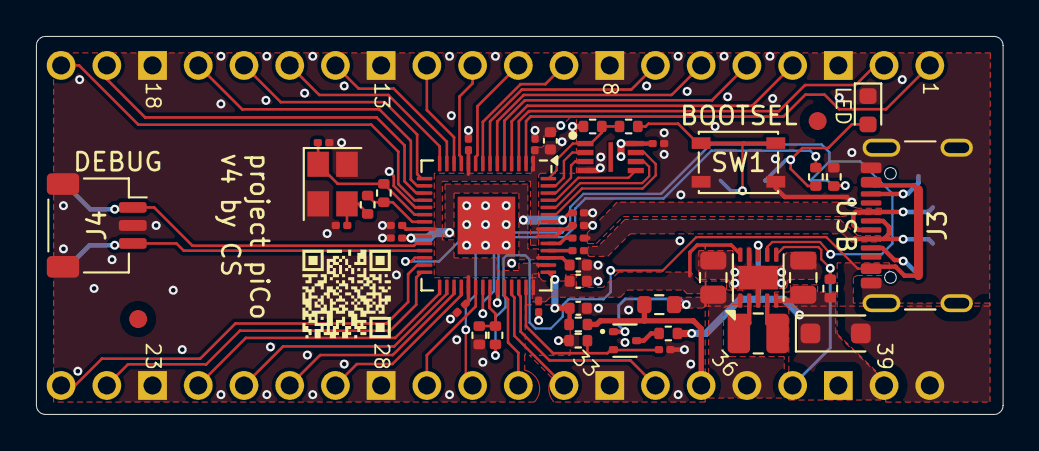
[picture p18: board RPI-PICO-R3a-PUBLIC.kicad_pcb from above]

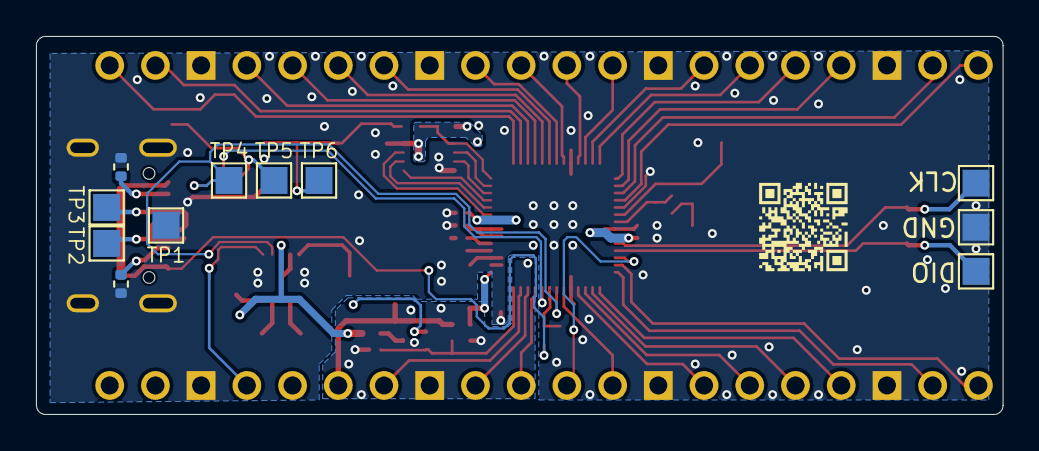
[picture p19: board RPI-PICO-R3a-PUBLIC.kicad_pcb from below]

Board: 2 copper layers, 53.7 x 21.0 mm, 59 parts (11 on the bottom side), 61 nets.

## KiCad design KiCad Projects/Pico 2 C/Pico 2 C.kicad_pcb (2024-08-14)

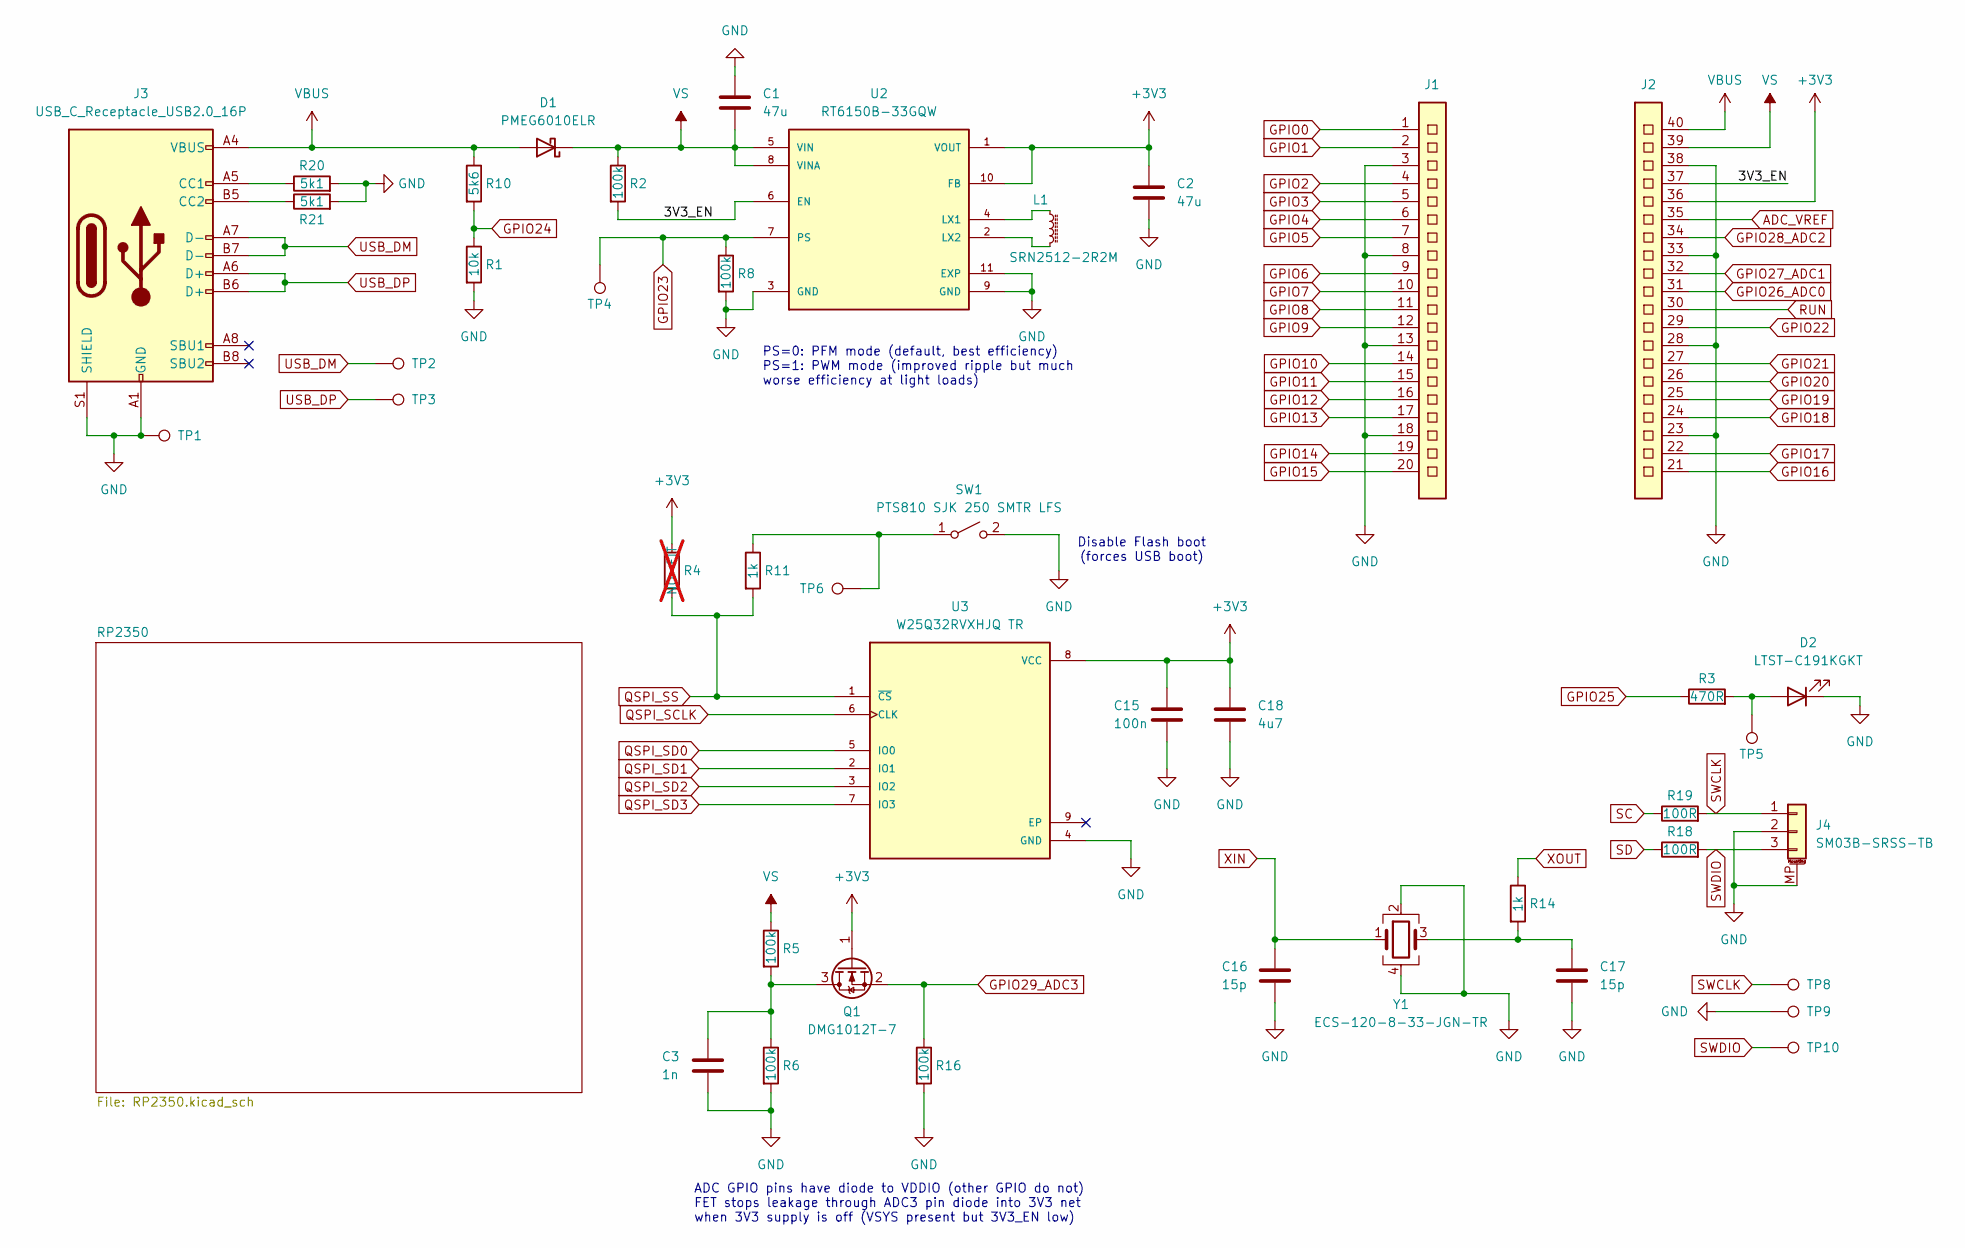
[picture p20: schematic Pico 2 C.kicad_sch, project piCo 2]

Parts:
C1, C2: 47u; C_0805_2012Metric
C3: 1n; C_0201_0603Metric
C15: 100n; C_0201_0603Metric
C16, C17: 15p; C_0201_0603Metric
C18: 4u7; C_0402_1005Metric
D1: PMEG6010ELR; D_SOD-123F
D2: LTST-C191KGKT; LED_0603_1608Metric
J1: CON_PICO_1-20
J2: CON_PICO_21-40
J3: USB_C_Receptacle_USB2.0_16P; USB_C_Receptacle_GCT_USB4105-xx-A_16P_TopMnt_Horizontal
J4: SM03B-SRSS-TB; JST_SH_SM03B-SRSS-TB_1x03-1MP_P1.00mm_Horizontal
L1: SRN2512-2R2M; L_1008_2520Metric
Q1: DMG1012T-7; SOT-523
R1: 10k; R_0201_0603Metric
R2, R5, R6, R8, R16: 100k; R_0201_0603Metric
R3: 470R; R_0201_0603Metric
R4: NO-FIT; R_0201_0603Metric; not fitted
R10: 5k6; R_0201_0603Metric
R11, R14: 1k; R_0201_0603Metric
R18, R19: 100R; R_0201_0603Metric
R20, R21: 5k1; R_0402_1005Metric
SW1: PTS810 SJK 250 SMTR LFS; SW_SPST_PTS810
TP1, TP2, TP3, TP4, TP5, TP6, TP8, TP9, TP10: TestPoint; TestPoint_Pad_1.5x1.5mm
U2: RT6150B-33GQW; DFN-10-1EP_2.6x2.6mm_P0.5mm_EP1.3x2.2mm
U3: W25Q32RVXHJQ TR; TDFN-8-1EP_3x2mm_P0.5mm_EP1.3x1.4mm
Y1: ECS-120-8-33-JGN-TR; Crystal_SMD_SeikoEpson_FA238-4Pin_3.2x2.5mm

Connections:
+3V3: C2.1, C15.1, C18.1, J2.36, Q1.1 (G), R4.1, U2.1 (VOUT), U2.10 (FB), U3.8 (VCC); also elsewhere on the board
/3V3_EN: J2.37, R2.2, U2.6 (EN)
ADC_VREF: J2.35; also elsewhere on the board
GND: C1.2, C2.2, C3.2, C15.2, C16.2, C17.2, C18.2, D2.1 (K), J1.3, J1.8, J1.13, J1.18, J2.23, J2.28, J2.33, J2.38, J3.A1 (GND), J3.A12 (GND), J3.B1 (GND), J3.B12 (GND), J3.S1 (SHIELD), J4.2, J4.MP (MountPin), R1.2, R6.2, R8.2, R16.2, R20.2, R21.2, SW1.2 (B), TP1.1, TP9.1, U2.3 (GND), U2.9 (GND), U2.11 (EXP), U3.4 (GND), Y1.2, Y1.4; also elsewhere on the board
GPIO0: J1.1; also elsewhere on the board
GPIO1: J1.2; also elsewhere on the board
GPIO2: J1.4; also elsewhere on the board
GPIO3: J1.5; also elsewhere on the board
GPIO4: J1.6; also elsewhere on the board
GPIO5: J1.7; also elsewhere on the board
GPIO6: J1.9; also elsewhere on the board
GPIO7: J1.10; also elsewhere on the board
GPIO8: J1.11; also elsewhere on the board
GPIO9: J1.12; also elsewhere on the board
GPIO10: J1.14; also elsewhere on the board
GPIO11: J1.15; also elsewhere on the board
GPIO12: J1.16; also elsewhere on the board
GPIO13: J1.17; also elsewhere on the board
GPIO14: J1.19; also elsewhere on the board
GPIO15: J1.20; also elsewhere on the board
GPIO16: J2.21; also elsewhere on the board
GPIO17: J2.22; also elsewhere on the board
GPIO18: J2.24; also elsewhere on the board
GPIO19: J2.25; also elsewhere on the board
GPIO20: J2.26; also elsewhere on the board
GPIO21: J2.27; also elsewhere on the board
GPIO22: J2.29; also elsewhere on the board
GPIO23: R8.1, TP4.1, U2.7 (PS); also elsewhere on the board
GPIO24: R1.1, R10.2; also elsewhere on the board
GPIO25: R3.1; also elsewhere on the board
GPIO26_ADC0: J2.31; also elsewhere on the board
GPIO27_ADC1: J2.32; also elsewhere on the board
GPIO28_ADC2: J2.34; also elsewhere on the board
GPIO29_ADC3: Q1.2 (S), R16.1; also elsewhere on the board
unnamed: C17.1, R14.2, Y1.3
unnamed: D2.2 (A), R3.2, TP5.1
unnamed: J3.A5 (CC1), R20.1
unnamed: J3.B5 (CC2), R21.1
unnamed: C3.1, Q1.3 (D), R5.2, R6.1
unnamed: R11.1, SW1.1 (A), TP6.1
unnamed: L1.1, U2.4 (LX1)
unnamed: L1.2, U2.2 (LX2)
QSPI_SCLK: U3.6 (CLK); also elsewhere on the board
QSPI_SD0: U3.5 (IO0); also elsewhere on the board
QSPI_SD1: U3.2 (IO1); also elsewhere on the board
QSPI_SD2: U3.3 (IO2); also elsewhere on the board
QSPI_SD3: U3.7 (IO3); also elsewhere on the board
QSPI_SS: R4.2, R11.2, U3.1 (~CS); also elsewhere on the board
RUN: J2.30; also elsewhere on the board
SC: R19.1; also elsewhere on the board
SD: R18.1; also elsewhere on the board
SWCLK: J4.1, R19.2, TP8.1
SWDIO: J4.3, R18.2, TP10.1
USB_DM: J3.A7 (D-), J3.B7 (D-), TP2.1; also elsewhere on the board
USB_DP: J3.A6 (D+), J3.B6 (D+), TP3.1; also elsewhere on the board
VBUS: D1.2 (A), J2.40, J3.A4 (VBUS), J3.A9 (VBUS), J3.B4 (VBUS), J3.B9 (VBUS), R10.1
VS: C1.1, D1.1 (K), J2.39, R2.1, R5.1, U2.5 (VIN), U2.8 (VINA)
XIN: C16.1, Y1.1; also elsewhere on the board
XOUT: R14.1; also elsewhere on the board

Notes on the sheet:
ADC GPIO pins have diode to VDDIO (other GPIO do not) FET stops leakage through ADC3 pin diode into 3V3 net when 3V3 supply is off (VSYS present but 3V3_EN low)
Disable Flash boot (forces USB boot)
PS=0: PFM mode (default, best efficiency) PS=1: PWM mode (improved ripple but much worse efficiency at light loads)

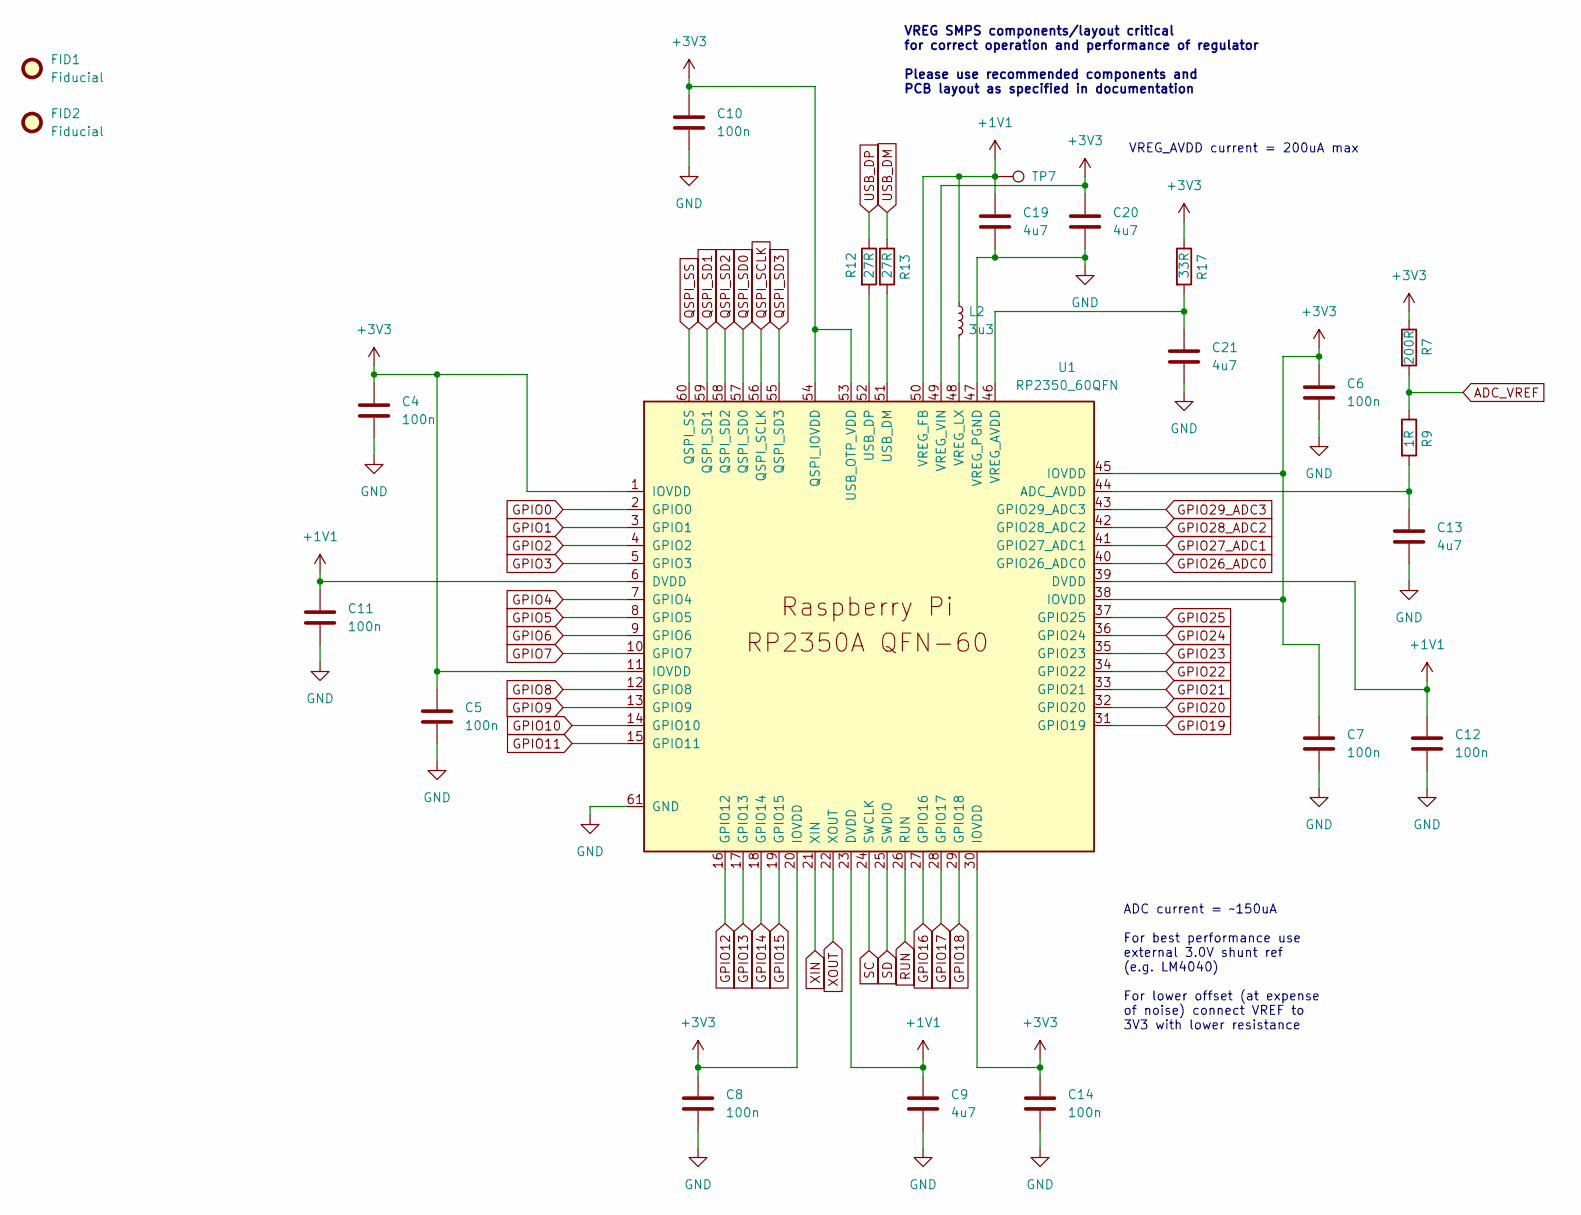
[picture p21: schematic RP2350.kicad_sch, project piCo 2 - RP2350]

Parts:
C4, C5, C6, C7, C8, C10, C11, C12, C14: 100n; C_0201_0603Metric
C9: 4u7; C_0201_0603Metric
C13, C19, C20, C21: 4u7; C_0402_1005Metric
FID1, FID2: Fiducial; Fiducial_1mm_Mask2mm
L2: 3u3; L_0603_1608Metric
R7: 200R; R_0402_1005Metric
R9: 1R; R_0201_0603Metric
R12, R13: 27R; R_0201_0603Metric
R17: 33R; R_0402_1005Metric
TP7: TestPoint; TestPoint_Pad_1.5x1.5mm
U1: RP2350_60QFN; RP2350-QFN-60-1EP_7x7_P0.4mm_EP3.4x3.4mm_ThermalVias

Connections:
+1V1: C9.1, C11.1, C12.1, C19.1, L2.1, TP7.1, U1.6 (DVDD), U1.23 (DVDD), U1.39 (DVDD), U1.50 (VREG_FB)
+3V3: C4.1, C5.1, C6.1, C7.1, C8.1, C10.1, C14.1, C20.1, R7.1, R17.1, U1.1 (IOVDD), U1.11 (IOVDD), U1.20 (IOVDD), U1.30 (IOVDD), U1.38 (IOVDD), U1.45 (IOVDD), U1.49 (VREG_VIN), U1.53 (USB_OTP_VDD), U1.54 (QSPI_IOVDD); also elsewhere on the board
ADC_VREF: R7.2, R9.1; also elsewhere on the board
GND: C4.2, C5.2, C6.2, C7.2, C8.2, C9.2, C10.2, C11.2, C12.2, C13.2, C14.2, C19.2, C20.2, C21.2, U1.47 (VREG_PGND), U1.61 (GND); also elsewhere on the board
GPIO0: U1.2 (GPIO0); also elsewhere on the board
GPIO1: U1.3 (GPIO1); also elsewhere on the board
GPIO2: U1.4 (GPIO2); also elsewhere on the board
GPIO3: U1.5 (GPIO3); also elsewhere on the board
GPIO4: U1.7 (GPIO4); also elsewhere on the board
GPIO5: U1.8 (GPIO5); also elsewhere on the board
GPIO6: U1.9 (GPIO6); also elsewhere on the board
GPIO7: U1.10 (GPIO7); also elsewhere on the board
GPIO8: U1.12 (GPIO8); also elsewhere on the board
GPIO9: U1.13 (GPIO9); also elsewhere on the board
GPIO10: U1.14 (GPIO10); also elsewhere on the board
GPIO11: U1.15 (GPIO11); also elsewhere on the board
GPIO12: U1.16 (GPIO12); also elsewhere on the board
GPIO13: U1.17 (GPIO13); also elsewhere on the board
GPIO14: U1.18 (GPIO14); also elsewhere on the board
GPIO15: U1.19 (GPIO15); also elsewhere on the board
GPIO16: U1.27 (GPIO16); also elsewhere on the board
GPIO17: U1.28 (GPIO17); also elsewhere on the board
GPIO18: U1.29 (GPIO18); also elsewhere on the board
GPIO19: U1.31 (GPIO19); also elsewhere on the board
GPIO20: U1.32 (GPIO20); also elsewhere on the board
GPIO21: U1.33 (GPIO21); also elsewhere on the board
GPIO22: U1.34 (GPIO22); also elsewhere on the board
GPIO23: U1.35 (GPIO23); also elsewhere on the board
GPIO24: U1.36 (GPIO24); also elsewhere on the board
GPIO25: U1.37 (GPIO25); also elsewhere on the board
GPIO26_ADC0: U1.40 (GPIO26_ADC0); also elsewhere on the board
GPIO27_ADC1: U1.41 (GPIO27_ADC1); also elsewhere on the board
GPIO28_ADC2: U1.42 (GPIO28_ADC2); also elsewhere on the board
GPIO29_ADC3: U1.43 (GPIO29_ADC3); also elsewhere on the board
unnamed: C13.1, R9.2, U1.44 (ADC_AVDD)
unnamed: R13.2, U1.51 (USB_DM)
unnamed: R12.2, U1.52 (USB_DP)
unnamed: C21.1, R17.2, U1.46 (VREG_AVDD)
unnamed: L2.2, U1.48 (VREG_LX)
QSPI_SCLK: U1.56 (QSPI_SCLK); also elsewhere on the board
QSPI_SD0: U1.57 (QSPI_SD0); also elsewhere on the board
QSPI_SD1: U1.59 (QSPI_SD1); also elsewhere on the board
QSPI_SD2: U1.58 (QSPI_SD2); also elsewhere on the board
QSPI_SD3: U1.55 (QSPI_SD3); also elsewhere on the board
QSPI_SS: U1.60 (QSPI_SS); also elsewhere on the board
RUN: U1.26 (RUN); also elsewhere on the board
SC: U1.24 (SWCLK); also elsewhere on the board
SD: U1.25 (SWDIO); also elsewhere on the board
USB_DM: R13.1; also elsewhere on the board
USB_DP: R12.1; also elsewhere on the board
XIN: U1.21 (XIN); also elsewhere on the board
XOUT: U1.22 (XOUT); also elsewhere on the board

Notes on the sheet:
VREG SMPS components/layout critical for correct operation and performance of regulator Please use recommended components and PCB layout as specified in documentation
ADC current = ~150uA For best performance use external 3.0V shunt ref (e.g. LM4040) For lower offset (at expense of noise) connect VREF to 3V3 with lower resistance
VREG_AVDD current = 200uA max

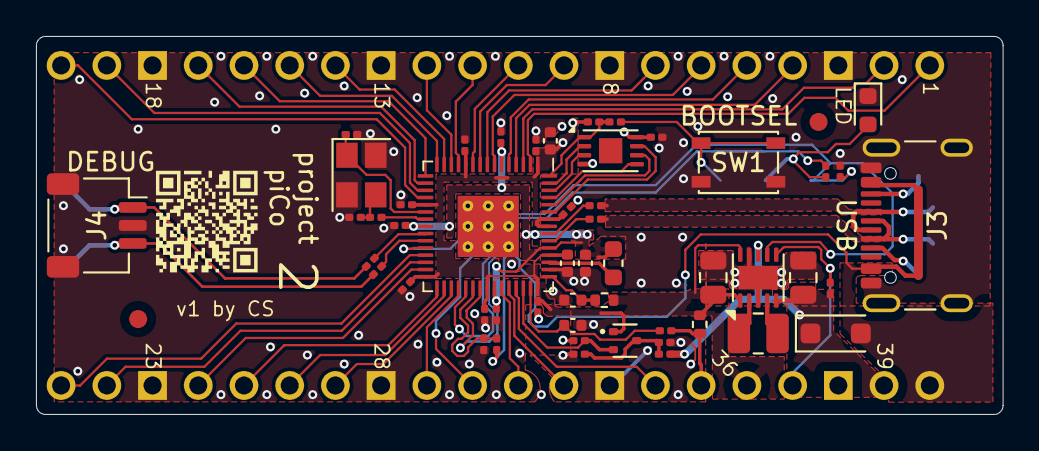
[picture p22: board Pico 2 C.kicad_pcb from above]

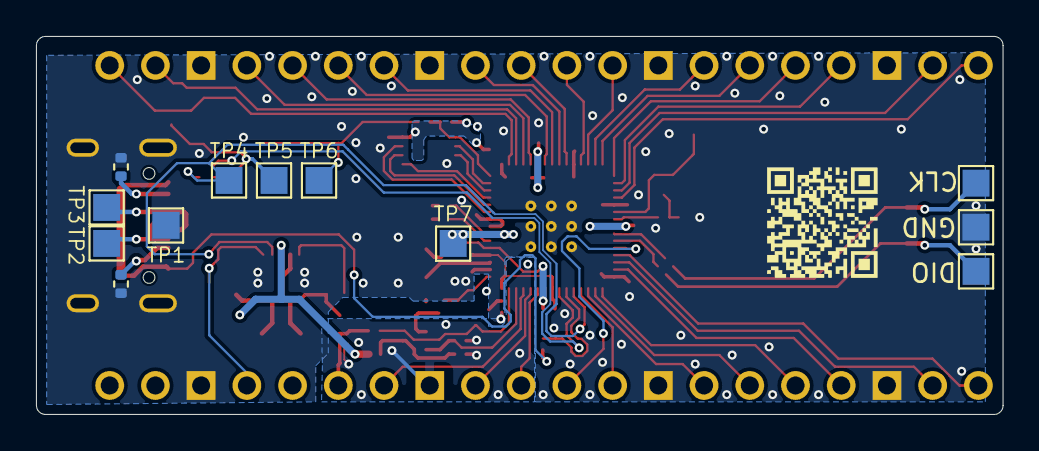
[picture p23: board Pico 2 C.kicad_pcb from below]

Board: 2 copper layers, 53.7 x 21.0 mm, 67 parts (12 on the bottom side), 65 nets.

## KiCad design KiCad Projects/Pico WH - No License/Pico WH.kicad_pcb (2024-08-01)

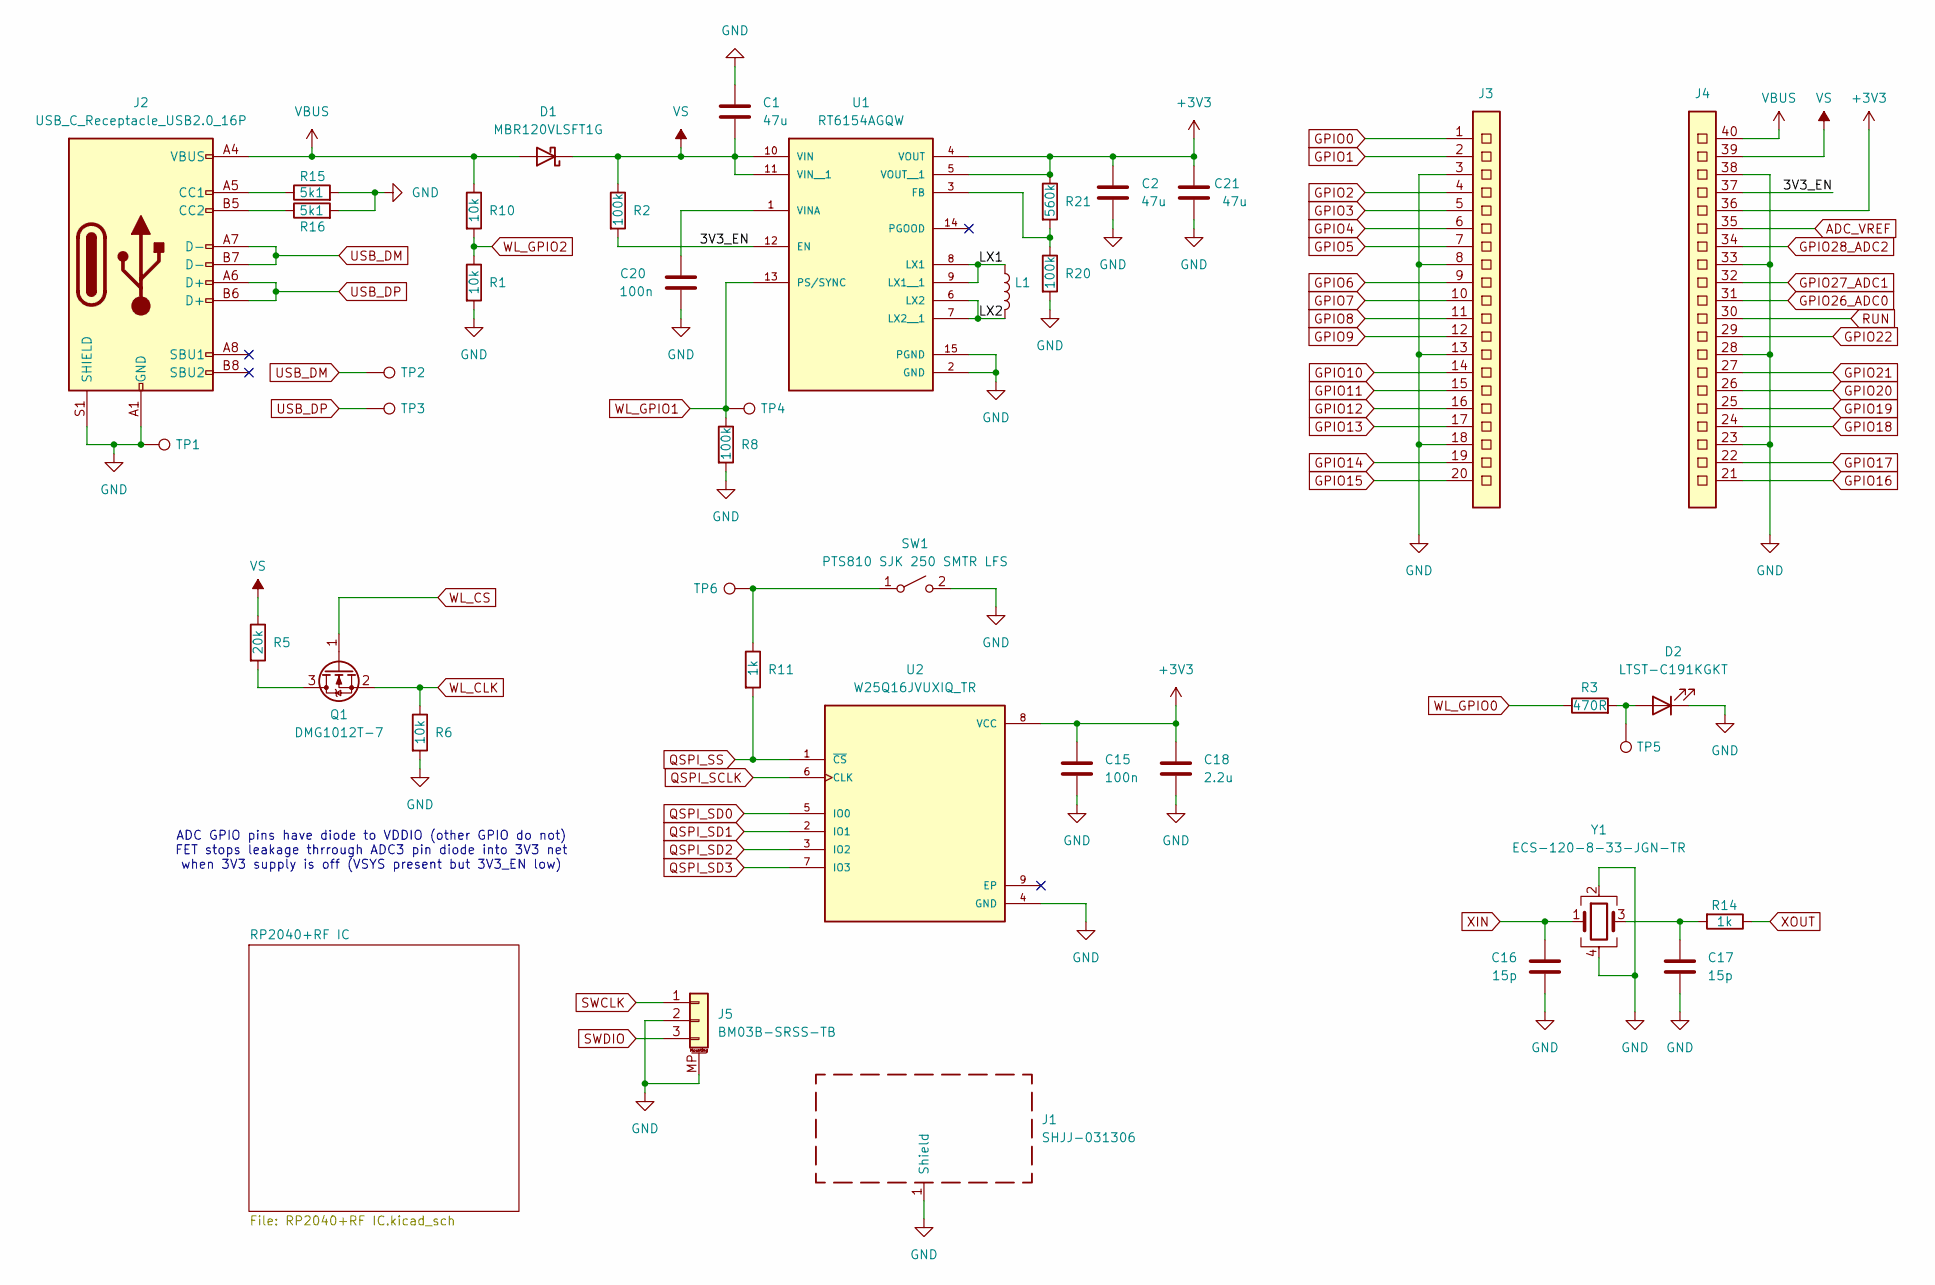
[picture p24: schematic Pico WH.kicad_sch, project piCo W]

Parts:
C1, C2, C21: 47u; C_0805_2012Metric
C15, C20: 100n; C_0201_0603Metric
C16, C17: 15p; C_0201_0603Metric
C18: 2.2u; C_0402_1005Metric
D1: MBR120VLSFT1G; D_SOD-123F
D2: LTST-C191KGKT; LED_0603_1608Metric
J1: SHJJ-031306; RF_SHIELD_PICOW
J2: USB_C_Receptacle_USB2.0_16P; USB_C_Receptacle_GCT_USB4105-xx-A_16P_TopMnt_Horizontal
J3: CON_PICO_1-20
J4: CON_PICO_21-40
J5: BM03B-SRSS-TB; JST_SH_BM03B-SRSS-TB_1x03-1MP_P1.00mm_Vertical
L1: SRN2512-1R0M; L_1008_2520Metric
Q1: DMG1012T-7; SOT-523
R1, R6, R10: 10k; R_0201_0603Metric
R2, R8, R20: 100k; R_0201_0603Metric
R3: 470R; R_0201_0603Metric
R5: 20k; R_0201_0603Metric
R11, R14: 1k; R_0201_0603Metric
R15, R16: 5k1; R_0402_1005Metric
R21: 560k; R_0201_0603Metric
SW1: PTS810 SJK 250 SMTR LFS; SW_SPST_PTS810
TP1, TP2, TP3, TP4, TP5, TP6: TestPoint; TestPoint_Pad_1.5x1.5mm
U1: RT6154AGQW; DFN-14-1EP_3x4mm_P0.5mm_EP1.7x3.3mm
U2: W25Q16JVUXIQ_TR; TDFN-8-1EP_3x2mm_P0.5mm_EP1.3x1.4mm
Y1: ECS-120-8-33-JGN-TR; Crystal_SMD_SeikoEpson_FA238-4Pin_3.2x2.5mm

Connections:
+3V3: C2.1, C15.1, C18.1, C21.1, J4.36, R21.1, U1.4 (VOUT), U1.5 (VOUT__1), U2.8 (VCC); also elsewhere on the board
/3V3_EN: J4.37, R2.2, U1.12 (EN)
/LX1: L1.1, U1.8 (LX1), U1.9 (LX1__1)
/LX2: L1.2, U1.6 (LX2), U1.7 (LX2__1)
ADC_VREF: J4.35; also elsewhere on the board
GND: C1.2, C2.2, C15.2, C16.2, C17.2, C18.2, C20.2, C21.2, D2.1 (K), J1.1 (Shield), J2.A1 (GND), J2.A12 (GND), J2.B1 (GND), J2.B12 (GND), J2.S1 (SHIELD), J3.3, J3.8, J3.13, J3.18, J4.23, J4.28, J4.33, J4.38, J5.2, J5.MP (MountPin), R1.2, R6.2, R8.2, R15.2, R16.2, R20.2, SW1.2 (B), TP1.1, U1.2 (GND), U1.15 (PGND), U2.4 (GND), Y1.2, Y1.4; also elsewhere on the board
GPIO0: J3.1; also elsewhere on the board
GPIO1: J3.2; also elsewhere on the board
GPIO2: J3.4; also elsewhere on the board
GPIO3: J3.5; also elsewhere on the board
GPIO4: J3.6; also elsewhere on the board
GPIO5: J3.7; also elsewhere on the board
GPIO6: J3.9; also elsewhere on the board
GPIO7: J3.10; also elsewhere on the board
GPIO8: J3.11; also elsewhere on the board
GPIO9: J3.12; also elsewhere on the board
GPIO10: J3.14; also elsewhere on the board
GPIO11: J3.15; also elsewhere on the board
GPIO12: J3.16; also elsewhere on the board
GPIO13: J3.17; also elsewhere on the board
GPIO14: J3.19; also elsewhere on the board
GPIO15: J3.20; also elsewhere on the board
GPIO16: J4.21; also elsewhere on the board
GPIO17: J4.22; also elsewhere on the board
GPIO18: J4.24; also elsewhere on the board
GPIO19: J4.25; also elsewhere on the board
GPIO20: J4.26; also elsewhere on the board
GPIO21: J4.27; also elsewhere on the board
GPIO22: J4.29; also elsewhere on the board
GPIO26_ADC0: J4.31; also elsewhere on the board
GPIO27_ADC1: J4.32; also elsewhere on the board
GPIO28_ADC2: J4.34; also elsewhere on the board
unnamed: C17.1, R14.2, Y1.3
unnamed: D2.2 (A), R3.2, TP5.1
unnamed: J2.A5 (CC1), R15.1
unnamed: J2.B5 (CC2), R16.1
unnamed: Q1.3 (D), R5.2
unnamed: R11.1, SW1.1 (A), TP6.1
unnamed: R20.1, R21.2, U1.3 (FB)
unnamed: C20.1, U1.1 (VINA)
QSPI_SCLK: U2.6 (CLK); also elsewhere on the board
QSPI_SD0: U2.5 (IO0); also elsewhere on the board
QSPI_SD1: U2.2 (IO1); also elsewhere on the board
QSPI_SD2: U2.3 (IO2); also elsewhere on the board
QSPI_SD3: U2.7 (IO3); also elsewhere on the board
QSPI_SS: R11.2, U2.1 (~CS); also elsewhere on the board
RUN: J4.30; also elsewhere on the board
SWCLK: J5.1; also elsewhere on the board
SWDIO: J5.3; also elsewhere on the board
USB_DM: J2.A7 (D-), J2.B7 (D-), TP2.1; also elsewhere on the board
USB_DP: J2.A6 (D+), J2.B6 (D+), TP3.1; also elsewhere on the board
VBUS: D1.2 (A), J2.A4 (VBUS), J2.A9 (VBUS), J2.B4 (VBUS), J2.B9 (VBUS), J4.40, R10.1
VS: C1.1, D1.1 (K), J4.39, R2.1, R5.1, U1.10 (VIN), U1.11 (VIN__1)
WL_CLK: Q1.2 (S), R6.1; also elsewhere on the board
WL_CS: Q1.1 (G); also elsewhere on the board
WL_GPIO0: R3.1; also elsewhere on the board
WL_GPIO1: R8.1, TP4.1, U1.13 (PS/SYNC); also elsewhere on the board
WL_GPIO2: R1.1, R10.2; also elsewhere on the board
XIN: C16.1, Y1.1; also elsewhere on the board
XOUT: R14.1; also elsewhere on the board

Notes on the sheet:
ADC GPIO pins have diode to VDDIO (other GPIO do not) FET stops leakage thrrough ADC3 pin diode into 3V3 net when 3V3 supply is off (VSYS present but 3V3_EN low)

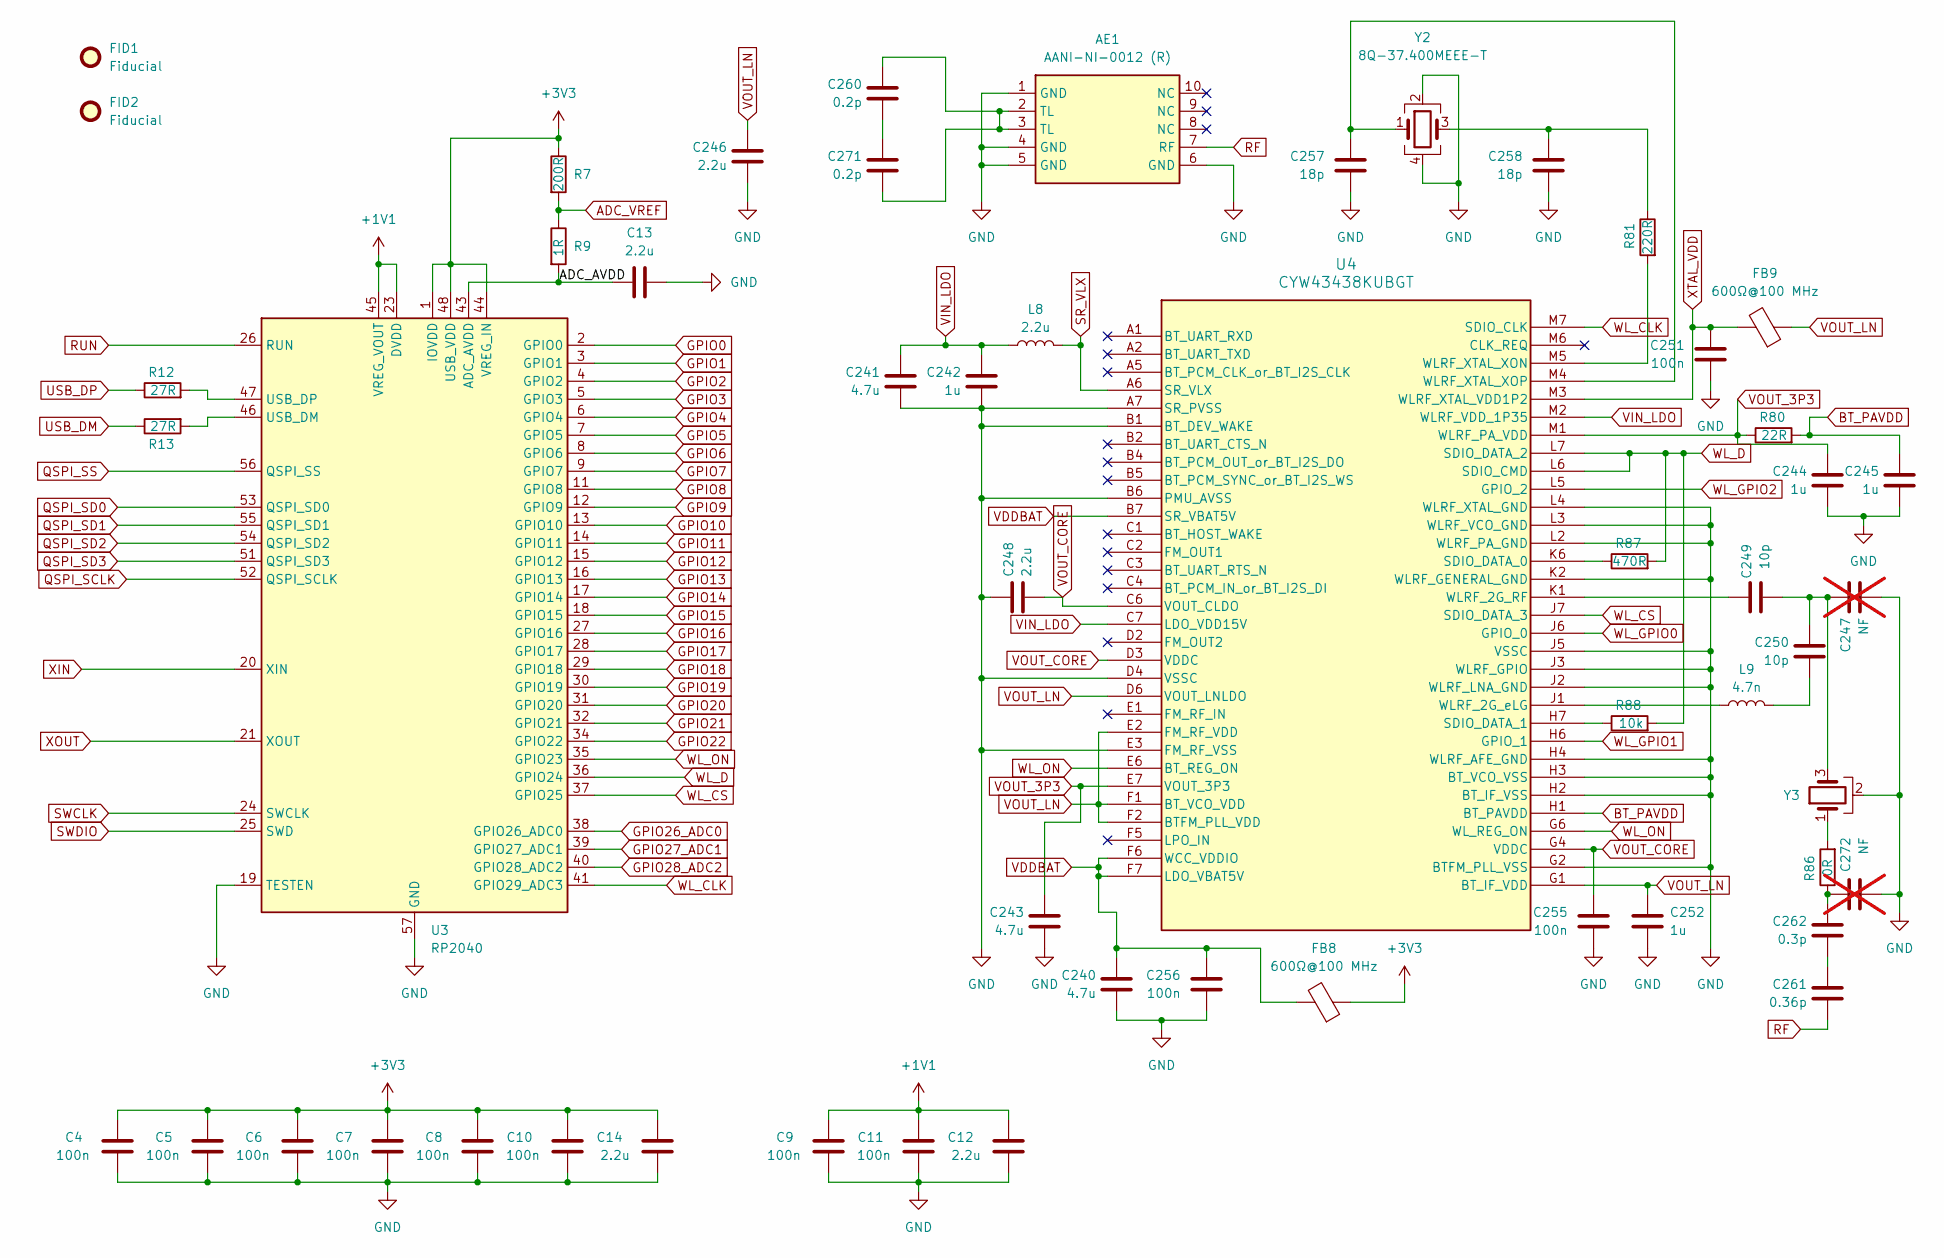
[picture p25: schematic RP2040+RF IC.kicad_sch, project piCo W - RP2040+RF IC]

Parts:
AE1: AANI-NI-0012 (R); AANI-NI-0012
C4, C5, C6, C7, C8, C9, C10, C11, C251, C255, C256: 100n; C_0201_0603Metric
C12, C13, C14, C246, C248: 2.2u; C_0402_1005Metric
C240, C241, C243: 4.7u; C_0402_1005Metric
C242, C244, C245, C252: 1u; C_0201_0603Metric
C247, C272: NF; C_0201_0603Metric; not fitted
C249, C250: 10p; C_0201_0603Metric
C257, C258: 18p; C_0201_0603Metric
C260, C271: 0.2p; C_0402_1005Metric
C261: 0.36p; C_0402_1005Metric
C262: 0.3p; C_0402_1005Metric
FB8: 600Ω@100 MHz; L_0603_1608Metric
FB9: 600Ω@100 MHz; L_0201_0603Metric
FID1, FID2: Fiducial; Fiducial_1mm_Mask2mm
L8: 2.2u; L_0603_1608Metric
L9: 4.7n; L_0201_0603Metric
R7: 200R; R_0603_1608Metric
R9: 1R; R_0402_1005Metric
R12, R13: 27R; R_0201_0603Metric
R80: 22R; R_0201_0603Metric
R81: 220R; R_0201_0603Metric
R86: 0R; R_0201_0603Metric
R87: 470R; R_0201_0603Metric
R88: 10k; R_0201_0603Metric
U3: RP2040; QFN-56-1EP_7x7mm_P0.4mm_EP3.2x3.2mm
U4: CYW43438KUBGT; BGA-63
Y2: 8Q-37.400MEEE-T; Oscillator_SMD_Abracon_ASCO-4Pin_1.6x1.2mm
Y3: LFB212G45CG7D227; FILS3_MUR_LFB21XXCG2Q

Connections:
+1V1: C9.1, C11.1, C12.1, U3.23 (DVDD), U3.45 (VREG_VOUT), U3.50 (DVDD)
+3V3: C4.1, C5.1, C6.1, C7.1, C8.1, C10.1, C14.1, FB8.1, R7.1, U3.1 (IOVDD), U3.10 (IOVDD), U3.22 (IOVDD), U3.33 (IOVDD), U3.42 (IOVDD), U3.44 (VREG_IN), U3.48 (USB_VDD), U3.49 (IOVDD); also elsewhere on the board
/RP2040+RF IC/ADC_AVDD: C13.1, R9.2, U3.43 (ADC_AVDD)
ADC_VREF: R7.2, R9.1; also elsewhere on the board
BT_PAVDD: C245.1, R80.2, U4.H1 (BT_PAVDD)
GND: AE1.1 (GND), AE1.4 (GND), AE1.5 (GND), AE1.6 (GND), C4.2, C5.2, C6.2, C7.2, C8.2, C9.2, C10.2, C11.2, C12.2, C13.2, C14.2, C240.2, C241.2, C242.2, C243.2, C244.2, C245.2, C246.2, C247.1, C248.2, C251.2, C252.2, C255.2, C256.2, C257.2, C258.2, C272.2, U3.19 (TESTEN), U3.57 (GND), U4.A7 (SR_PVSS), U4.B1 (BT_DEV_WAKE), U4.B6 (PMU_AVSS), U4.D4 (VSSC), U4.E3 (FM_RF_VSS), U4.G2 (BTFM_PLL_VSS), U4.H2 (BT_IF_VSS), U4.H3 (BT_VCO_VSS), U4.H4 (WLRF_AFE_GND), U4.J2 (WLRF_LNA_GND), U4.J3 (WLRF_GPIO), U4.J5 (VSSC), U4.K2 (WLRF_GENERAL_GND), U4.L2 (WLRF_PA_GND), U4.L3 (WLRF_VCO_GND), U4.L4 (WLRF_XTAL_GND), Y2.2, Y2.4, Y3.2; also elsewhere on the board
GPIO0: U3.2 (GPIO0); also elsewhere on the board
GPIO1: U3.3 (GPIO1); also elsewhere on the board
GPIO2: U3.4 (GPIO2); also elsewhere on the board
GPIO3: U3.5 (GPIO3); also elsewhere on the board
GPIO4: U3.6 (GPIO4); also elsewhere on the board
GPIO5: U3.7 (GPIO5); also elsewhere on the board
GPIO6: U3.8 (GPIO6); also elsewhere on the board
GPIO7: U3.9 (GPIO7); also elsewhere on the board
GPIO8: U3.11 (GPIO8); also elsewhere on the board
GPIO9: U3.12 (GPIO9); also elsewhere on the board
GPIO10: U3.13 (GPIO10); also elsewhere on the board
GPIO11: U3.14 (GPIO11); also elsewhere on the board
GPIO12: U3.15 (GPIO12); also elsewhere on the board
GPIO13: U3.16 (GPIO13); also elsewhere on the board
GPIO14: U3.17 (GPIO14); also elsewhere on the board
GPIO15: U3.18 (GPIO15); also elsewhere on the board
GPIO16: U3.27 (GPIO16); also elsewhere on the board
GPIO17: U3.28 (GPIO17); also elsewhere on the board
GPIO18: U3.29 (GPIO18); also elsewhere on the board
GPIO19: U3.30 (GPIO19); also elsewhere on the board
GPIO20: U3.31 (GPIO20); also elsewhere on the board
GPIO21: U3.32 (GPIO21); also elsewhere on the board
GPIO22: U3.34 (GPIO22); also elsewhere on the board
GPIO26_ADC0: U3.38 (GPIO26_ADC0); also elsewhere on the board
GPIO27_ADC1: U3.39 (GPIO27_ADC1); also elsewhere on the board
GPIO28_ADC2: U3.40 (GPIO28_ADC2); also elsewhere on the board
unnamed: AE1.2 (TL), AE1.3 (TL), C260.1, C271.2
unnamed: C247.2, C249.1, C250.1, Y3.3
unnamed: C250.2, L9.1
unnamed: C258.1, R81.1, Y2.3
unnamed: C260.2, C271.1
unnamed: C261.1, C262.1
unnamed: C262.2, C272.1, R86.1
unnamed: R86.2, Y3.1
unnamed: R13.2, U3.46 (USB_DM)
unnamed: R12.2, U3.47 (USB_DP)
unnamed: R87.1, U4.K6 (SDIO_DATA_0)
unnamed: R88.1, U4.H7 (SDIO_DATA_1)
unnamed: C249.2, U4.K1 (WLRF_2G_RF)
unnamed: L9.2, U4.J1 (WLRF_2G_eLG)
unnamed: R81.2, U4.M5 (WLRF_XTAL_XON)
unnamed: C257.1, U4.M4 (WLRF_XTAL_XOP), Y2.1
QSPI_SCLK: U3.52 (QSPI_SCLK); also elsewhere on the board
QSPI_SD0: U3.53 (QSPI_SD0); also elsewhere on the board
QSPI_SD1: U3.55 (QSPI_SD1); also elsewhere on the board
QSPI_SD2: U3.54 (QSPI_SD2); also elsewhere on the board
QSPI_SD3: U3.51 (QSPI_SD3); also elsewhere on the board
QSPI_SS: U3.56 (QSPI_SS); also elsewhere on the board
RF: AE1.7 (RF), C261.2
RUN: U3.26 (RUN); also elsewhere on the board
SR_VLX: L8.1, U4.A6 (SR_VLX)
SWCLK: U3.24 (SWCLK); also elsewhere on the board
SWDIO: U3.25 (SWD); also elsewhere on the board
USB_DM: R13.1; also elsewhere on the board
USB_DP: R12.1; also elsewhere on the board
VDDBAT: C240.1, C256.1, FB8.2, U4.B7 (SR_VBAT5V), U4.F6 (WCC_VDDIO), U4.F7 (LDO_VBAT5V)
VIN_LDO: C241.1, C242.1, L8.2, U4.C7 (LDO_VDD15V), U4.M2 (WLRF_VDD_1P35)
VOUT_3P3: C243.1, C244.1, R80.1, U4.E7 (VOUT_3P3), U4.M1 (WLRF_PA_VDD)
VOUT_CORE: C248.1, C255.1, U4.C6 (VOUT_CLDO), U4.D3 (VDDC), U4.G4 (VDDC)
VOUT_LN: C246.1, C252.1, FB9.1, U4.D6 (VOUT_LNLDO), U4.E2 (FM_RF_VDD), U4.F1 (BT_VCO_VDD), U4.F2 (BTFM_PLL_VDD), U4.G1 (BT_IF_VDD)
WL_CLK: U3.41 (GPIO29_ADC3), U4.M7 (SDIO_CLK); also elsewhere on the board
WL_CS: U3.37 (GPIO25), U4.J7 (SDIO_DATA_3); also elsewhere on the board
WL_D: R87.2, R88.2, U3.36 (GPIO24), U4.L6 (SDIO_CMD), U4.L7 (SDIO_DATA_2)
WL_GPIO0: U4.J6 (GPIO_0); also elsewhere on the board
WL_GPIO1: U4.H6 (GPIO_1); also elsewhere on the board
WL_GPIO2: U4.L5 (GPIO_2); also elsewhere on the board
WL_ON: U3.35 (GPIO23), U4.E6 (BT_REG_ON), U4.G6 (WL_REG_ON)
XIN: U3.20 (XIN); also elsewhere on the board
XOUT: U3.21 (XOUT); also elsewhere on the board
XTAL_VDD: C251.1, FB9.2, U4.M3 (WLRF_XTAL_VDD1P2)

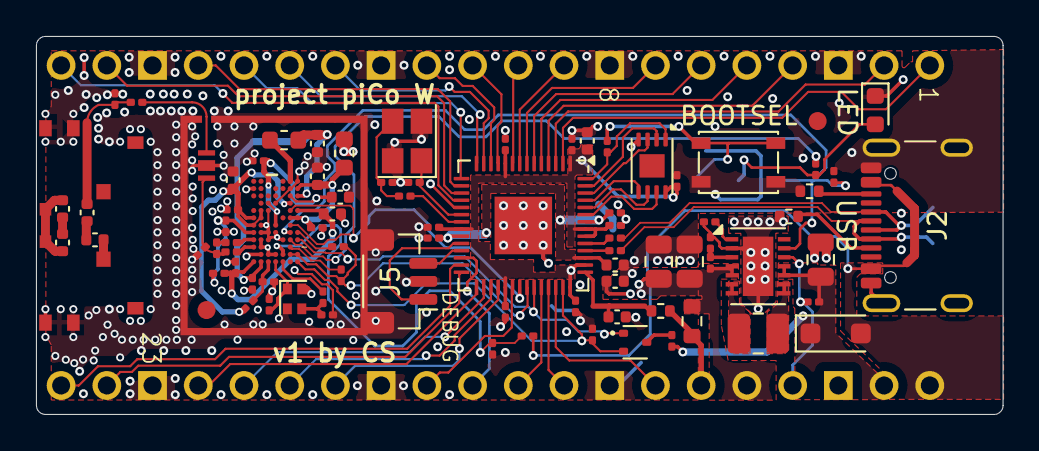
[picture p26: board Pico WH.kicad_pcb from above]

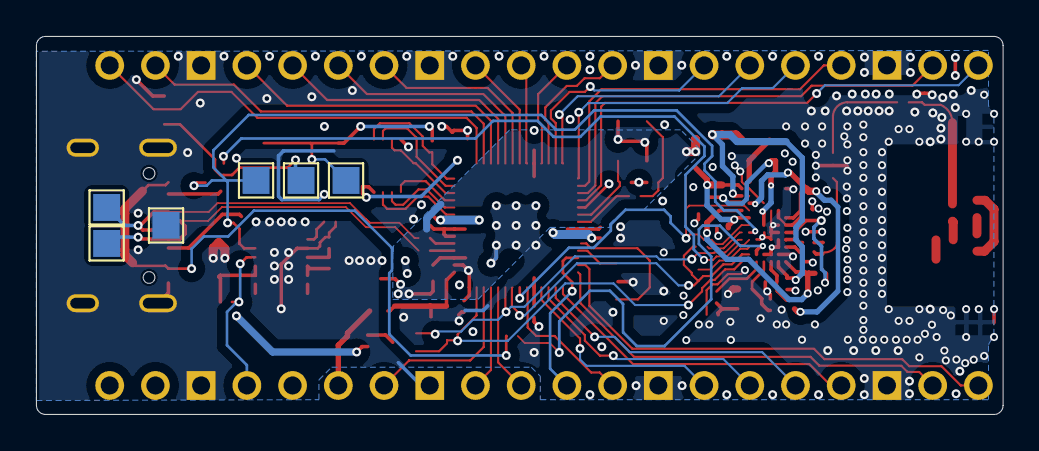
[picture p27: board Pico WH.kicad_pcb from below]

Board: 4 copper layers, 53.7 x 21.0 mm, 93 parts (6 on the bottom side), 89 nets.

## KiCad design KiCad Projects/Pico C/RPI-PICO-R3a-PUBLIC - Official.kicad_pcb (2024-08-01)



Board: 2 copper layers, 21.0 x 51.0 mm, 51 parts (6 on the bottom side), 59 nets.

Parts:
C1, C2: CAP_MLCC_CAPC2012_47U_RP-019A1P; CAPC2012
C3: CAP_MLCC_M0603_PICO_1N_RP-019A1; M0603_PICO
C4, C5, C6, C7, C8, C9, C10, C11, C15: CAP_MLCC_M0603_PICO_100N_RP-019; M0603_PICO
C12, C13, C14, C18: CAP_MLCC_CAPC1005_2U2_RP-019A1P; CAPC1005
C16, C17: CAP_MLCC_M0603_PICO_15P_RP-019A; M0603_PICO
D1: DIODE_SCHOTTKY_SOD123FL_MBR120V; SOD123FL
D2: LED_2PIN_AVAGO_QSM_GREEN_RP-019; AVAGO_QSM
J0: CON_PICO_40W_CON_PICO_40W_CON_P; CON_PICO_40W
J1: CON_UUSB_B_FCI_10103594-0001LF_; FCI_10103594-0001LF
J2: CON_PICO_3W_CON_PICO_3W_CON_PIC; CON_PICO_3W
L1: INDUCTOR_BOURNS_SRN2512_2U2_RP-; BOURNS_SRN2512
Q1: MOSFET_N_SOT50P160X90-3N_DMG101; SOT50P160X90-3N
R1: RES_CHIP_RESC1005_10K_RP-019A1P; RESC1005
R2, R6, R8: RES_CHIP_RESC1005_100K_RP-019A1; RESC1005
R3: RES_CHIP_RESC1005_470R_RP-019A1; RESC1005
R4, R15: RES_CHIP_RESC1005_NO-FIT_; RESC1005
R5: RES_CHIP_RESC1005_200K_RP-019A1; RESC1005
R7: RES_CHIP_RESC1608_200R_RP-01A5Y; RESC1608
R9: RES_CHIP_RESC1005_1R_RP-019A1P-; RESC1005
R10: RES_CHIP_RESC1005_5K6_RP-019A1P; RESC1005
R11, R14: RES_CHIP_RESC1005_1K_RP-019A1P-; RESC1005
R12, R13: RES_CHIP_M0603_PICO_27R_RP-019A; M0603_PICO
SW1: SW_PB_4PIN_TONEPARTS_TP-1221U-K; TONEPARTS_TP-1221U-K9K5325
TP1, TP2, TP3, TP4, TP5, TP6: TP_SMT_SQUARERC_1P5MM_TP_SMT_1P; TP_SMT_1P5X1P5MM
U1: RPI_RP2040_RPI_RP2040_RP2040; RPI_RP2040
U2: RICHTEK_RT6150_RICHTEK_RT6150B_; RICHTEK_RT6150B
U3: WINBOND_W25X_QSPI_FLASH_USON_US; USON_2X3MM
X1: CRYSTAL_4P_XTAL320X250X100_12MH; XTAL320X250X100

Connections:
1V1: C9.1, C11.1, C12.1, U1.23, U1.45, U1.50
3V3: C2.1, C4.1, C5.1, C6.1, C7.1, C8.1, C10.1, C14.1, C15.1, C18.1, J0.36, Q1.1, R4.1, R7.1, U1.1, U1.10, U1.22, U1.33, U1.42, U1.44, U1.48, U1.49, U2.1, U2.10, U3.8
3V3_EN: J0.37, R2.2, U2.6
ADC_AVDD: C13.1, R9.2, U1.43
ADC_VREF: J0.35, R7.2, R9.1
GND: C1.2, C2.2, C3.2, C4.2, C5.2, C6.2, C7.2, C8.2, C9.2, C10.2, C11.2, C12.2, C13.2, C14.2, C15.2, C16.2, C17.2, C18.2, D2.1, J0.3, J0.8, J0.13, J0.18, J0.23, J0.28, J0.33, J0.38, J1.5, J1.6, J1.7, J1.8, J1.9, J2.2, R1.2, R6.2, R8.2, SW1.3, SW1.4, TP1.1, U1.19, U1.57, U2.3, U2.9, U2.11, U3.4, X1.2, X1.4
GPIO0: J0.1, U1.2
GPIO1: J0.2, U1.3
GPIO2: J0.4, U1.4
GPIO3: J0.5, U1.5
GPIO4: J0.6, U1.6
GPIO5: J0.7, U1.7
GPIO6: J0.9, U1.8
GPIO7: J0.10, U1.9
GPIO8: J0.11, U1.11
GPIO9: J0.12, U1.12
GPIO10: J0.14, U1.13
GPIO11: J0.15, U1.14
GPIO12: J0.16, U1.15
GPIO13: J0.17, U1.16
GPIO14: J0.19, U1.17
GPIO15: J0.20, U1.18
GPIO16: J0.21, U1.27
GPIO17: J0.22, U1.28
GPIO18: J0.24, U1.29
GPIO19: J0.25, U1.30
GPIO20: J0.26, U1.31
GPIO21: J0.27, U1.32
GPIO22: J0.29, U1.34
GPIO23: R8.1, TP4.1, U1.35, U2.7
GPIO24: R1.1, R10.2, U1.36
GPIO25: R3.1, U1.37
GPIO26_ADC0: J0.31, U1.38
GPIO27_ADC1: J0.32, U1.39
GPIO28_ADC2: J0.34, U1.40
GPIO29_ADC3: Q1.2, U1.41
N1248345: L1.1, U2.4
N1248352: L1.2, U2.2
N1283798: D2.2, R3.2, TP5.1
N1286133: C3.1, Q1.3, R5.2, R6.1
N1327876: R11.1, SW1.1, SW1.2, TP6.1
QSPI_SCLK: U1.52, U3.6
QSPI_SD0: U1.53, U3.5
QSPI_SD1: U1.55, U3.2
QSPI_SD2: U1.54, U3.3
QSPI_SD3: U1.51, U3.7
QSPI_SS: R4.2, R11.2, U1.56, U3.1
RUN: J0.30, U1.26
SWCLK: J2.1, U1.24
SWDIO: J2.3, U1.25
USB_DM: J1.2, R13.1, TP2.1
USB_DMX: R13.2, U1.46
USB_DP: J1.3, R12.1, TP3.1
USB_DPX: R12.2, U1.47
VBUS: D1.2, J0.40, J1.1, R10.1
VSYS: C1.1, D1.1, J0.39, R2.1, R5.1, U2.5, U2.8
XIN: C16.1, R15.1, U1.20, X1.1
XOUT: R14.1, R15.2, U1.21
XR: C17.1, R14.2, X1.3

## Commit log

2024-01-25 Add files via upload
    Uploaded project files and license.
    [ABM3B-12.000MHZ-B2-T.step, DMG1012T-7.step, MBR120VLSFT1G.step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]
2024-01-25 Delete Pico C directory
    I edited the silkscreen so I'm purging this and adding the updated one because I don't know how to Git.
    [ABM3B-12.000MHZ-B2-T.step, DMG1012T-7.step, MBR120VLSFT1G.step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]
2024-01-25 Add files via upload
    Re-added project files.
    [ABM3B-12.000MHZ-B2-T.step, DMG1012T-7.step, MBR120VLSFT1G.step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]
2024-01-25 Update README.md
    Removed the redundant description since I saw it was on the side of the page and specified which version of KiCad I used.
2024-01-27 Delete Pico C directory
    I don't know how to just update the files that are here so I'm going to purge the old directory and upload the new one.
    [ABM3B-12.000MHZ-B2-T.step, DMG1012T-7.step, MBR120VLSFT1G.step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]
2024-01-27 Add files via upload
    Uploaded version 2 of the board
    [ABM3B-12.000MHZ-B2-T.step, DMG1012T-7.step, MBR120VLSFT1G.step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]
2024-01-27 Update README.md
    Updated the ReadMe to reflect version 2 of the board.
2024-02-08 Add files via upload
    Uploaded version 3 of the project
    [ABM3B-12.000MHZ-B2-T.step, DMG1012T-7.step, MBR120VLSFT1G.step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]
2024-02-08 Add files via upload
    Made a slight modification to a GND trace on the W25Q16JVUXIQ.
    [ABM3B-12.000MHZ-B2-T.step, DMG1012T-7.step, MBR120VLSFT1G.step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]
2024-02-08 Add files via upload
    Importing the project onto another computer caused weird errors with some of the STEP files, so I attempted to correct them and reupload the project.
    [ABM3B-12.000MHZ-B2-T.step, DMG1012T-7.step, MBR120VLSFT1G.step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]
2024-02-15 Add files via upload
    Corrected the footprint of the 12MHz oscillator.
    [ABM3B-12.000MHZ-B2-T.step, DMG1012T-7.step, ECS-120-8-33-JGN-TR.step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]
2024-02-15 Add files via upload
    Corrected USB data lines, confirmed the board functions.
    [ABM3B-12.000MHZ-B2-T.step, DMG1012T-7.step, ECS-120-8-33-JGN-TR.step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]
2024-02-27 Add files via upload
    Upload boardview file for use with OpenBoardView.
    [RP2040.kicad_sch, RPI-PICO-R3a-PUBLIC.brd, RPI-PICO-R3a-PUBLIC.kicad_pcb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]
2024-02-27 Add files via upload
    Changed VSS to VS to reflect that it is a system voltage and not a negative supply/GND.
    [RPI-PICO-R3a-PUBLIC.brd, RPI-PICO-R3a-PUBLIC.kicad_pcb, RPI-PICO-R3a-PUBLIC.kicad_sch]
2024-02-28 Add files via upload
    Updated design and included official design file from the Pi Foundation.
    [RPI-PICO-R3a-PUBLIC - Official.kicad_pcb, RPI-PICO-R3a-PUBLIC.brd, RPI-PICO-R3a-PUBLIC.kicad_pcb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]
2024-02-28 Update README.md
    Included `RPI-PICO-R3a-PUBLIC - Official.kicad_pcb` description and images.
2024-02-29 Add files via upload
    Slightly adjusted routing on GPIO3.
    [RPI-PICO-R3a-PUBLIC.kicad_pcb]
2024-03-02 Add files via upload
    Corrected pin 33 to actually be GND instead of a NC to GNDA.
    [RP2040.kicad_sch, RPI-PICO-R3a-PUBLIC.brd, RPI-PICO-R3a-PUBLIC.kicad_pcb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]
2024-03-02 Add files via upload
    Updated gerbers.
2024-03-03 Add files via upload
    Updated component references to more closely match the original Pico.
    [RP2040.kicad_sch, RPI-PICO-R3a-PUBLIC.brd, RPI-PICO-R3a-PUBLIC.kicad_pcb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]
2024-03-05 Add files via upload
    Changed resistor reference numbers to match the real Pico H.
    [RP2040.kicad_sch, RPI-PICO-R3a-PUBLIC.brd, RPI-PICO-R3a-PUBLIC.kicad_pcb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]
2024-03-05 Update README.md
    Updated ADC shunt resistor reference name.
2024-03-09 Delete Pico C/~RPI-PICO-R3a-PUBLIC.kicad_pcb.lck
    Importing this project would cause an error that the project was open on my computer
2024-03-09 Add files via upload
    Updated X1's footprint for schematic parity in DRC.
    [RPI-PICO-R3a-PUBLIC.kicad_pcb, RPI-PICO-R3a-PUBLIC.kicad_sch]
2024-03-09 Add files via upload
    Updated RPI-PICO-R3a-PUBLIC - Official.kicad_pcb to KiCad 8.
    [RPI-PICO-R3a-PUBLIC - Official.kicad_pcb]
2024-03-09 Update README.md
    Updated to reflect the project now being based on KiCad 8.
2024-03-12 Add files via upload
    Added Boardview file and OpenBoardData file.
    [RPI-PICO-R3a-PUBLIC.brd]
2024-03-23 Upload Boardview+OpenBoardData file for real Pico
2024-04-01 Updated boardview file outlines
    Used a simplified board outline for the boardview files.
2024-05-09 Footprint Modifications
    Changed the footprints to use included KiCad models where possible, removed unnecessary STEP files.
    [ABM3B-12.000MHZ-B2-T.step, ECS-120-8-33-JGN-TR.step, MBR120VLSFT1G.step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]
2024-05-09 Update RPI-PICO-R3a-PUBLIC.pdf
    Updated PDF copy of schematic.
2024-05-10 Updated schematic for crystal
    Updated the schematic symbol for the 12MHz crystal to be a KiCad included symbol.
    [RPI-PICO-R3a-PUBLIC.kicad_pcb, RPI-PICO-R3a-PUBLIC.kicad_sch]
2024-08-01 Added the Pico WH
    Refactored the repository to include the design files for the Pico WH.
    [8Q-37.400MEEE-T.step, BGA-63.step, BM03B-SRSS-TB-LF--SN---3DModel-STEP-56544.STEP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]
2024-08-01 Fixed dead links, added HTML BOM
    I fixed dead links that I made beforehand by prediction and I added an HTML BOM for the USB-C Pico H.
2024-08-14 Added Pico 2
    Added an initial design for the Pico 2. Also updated the original Pico C to v4 (without README update since I'm waiting on boards to ship).
    [DMG1012T-7.step, Pico 2 C.kicad_pcb, Pico 2 C.kicad_sch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]
2024-08-27 Updated main Pico to v4
    Updated the documentation to reflect v4 of the original Pico. Also added a `README` for the boardview files.

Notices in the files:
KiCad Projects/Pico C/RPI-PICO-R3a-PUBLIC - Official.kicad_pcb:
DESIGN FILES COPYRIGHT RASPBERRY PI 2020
